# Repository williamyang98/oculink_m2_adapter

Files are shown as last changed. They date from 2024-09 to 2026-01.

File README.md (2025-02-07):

# Introduction


Open source M.2 to Oculink adapter for the Lenovo Ideapad Pro 5 16ARP8 laptop. Includes a single board design and a flexible two board design.

Documentation on design, manufacturing and benchmarks can be found [here](https://williamyang98.github.io/oculink_m2_adapter/docs/)

## Single board design
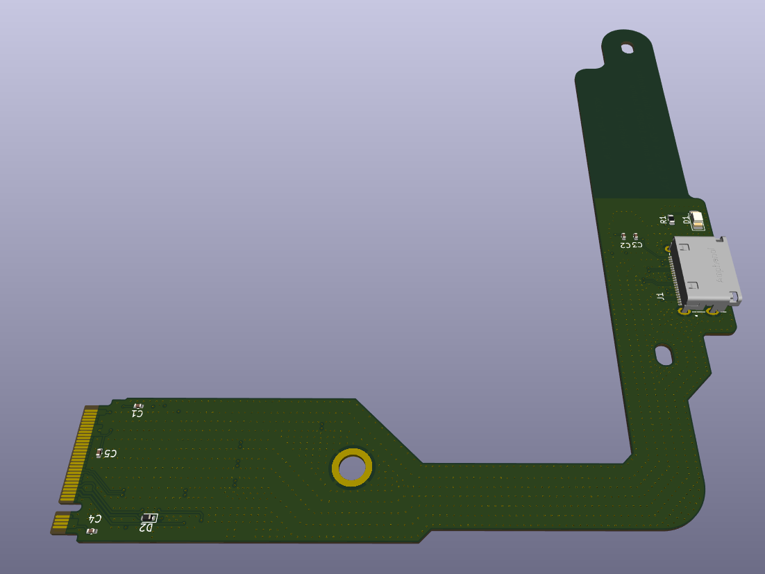
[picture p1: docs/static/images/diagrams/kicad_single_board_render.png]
Single board Oculink adapter render

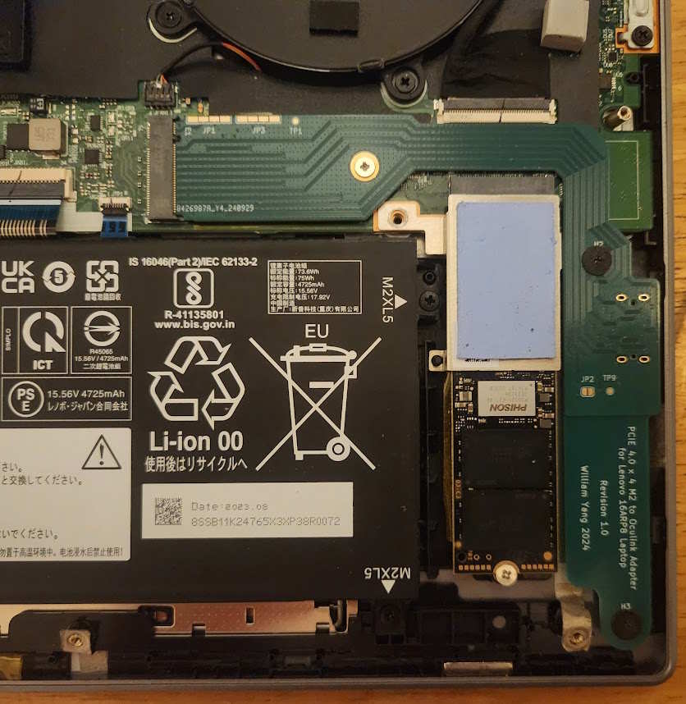
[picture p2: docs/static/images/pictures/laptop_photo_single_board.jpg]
Single board Oculink adapter


## Flexible two board design
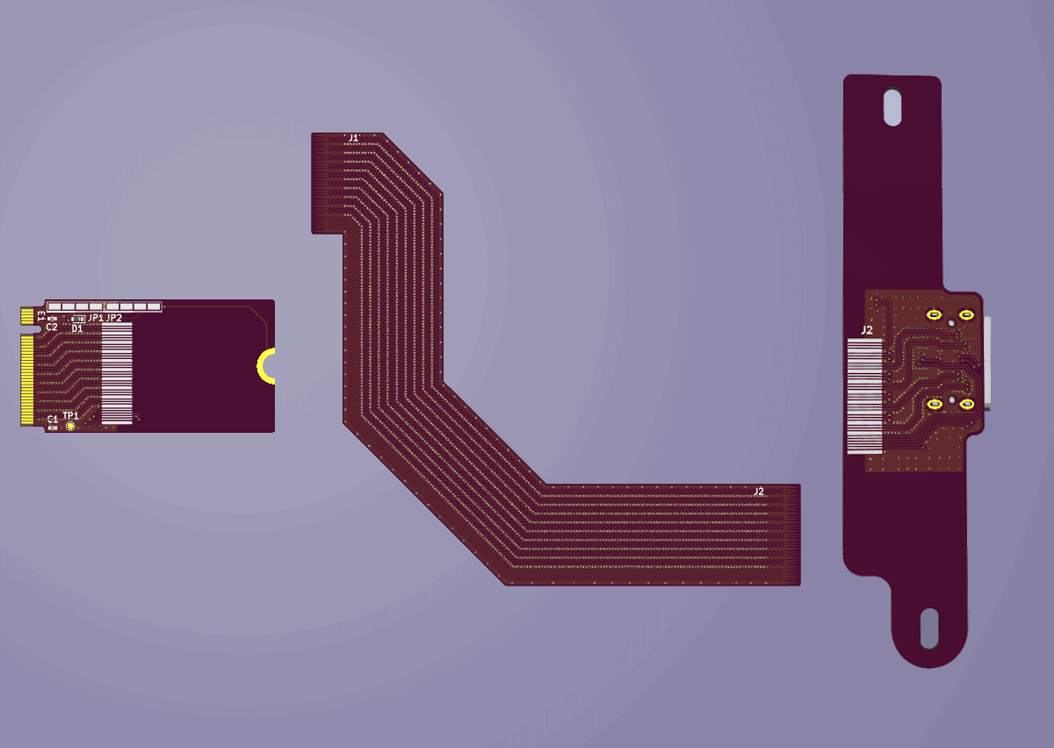
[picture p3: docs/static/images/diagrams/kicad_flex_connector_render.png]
Flexible PCB multipart Oculink adapter render

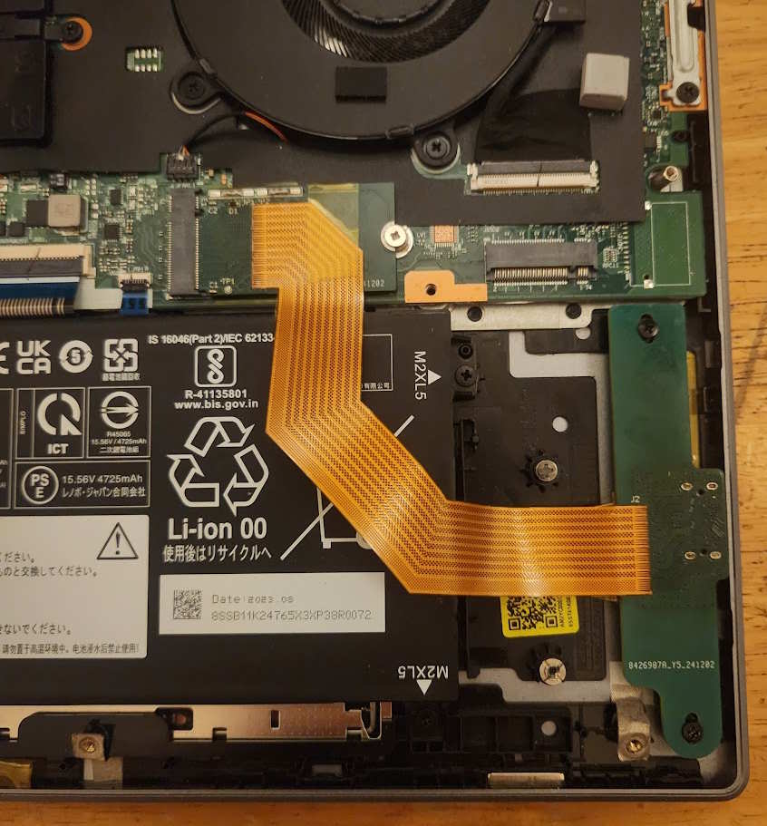
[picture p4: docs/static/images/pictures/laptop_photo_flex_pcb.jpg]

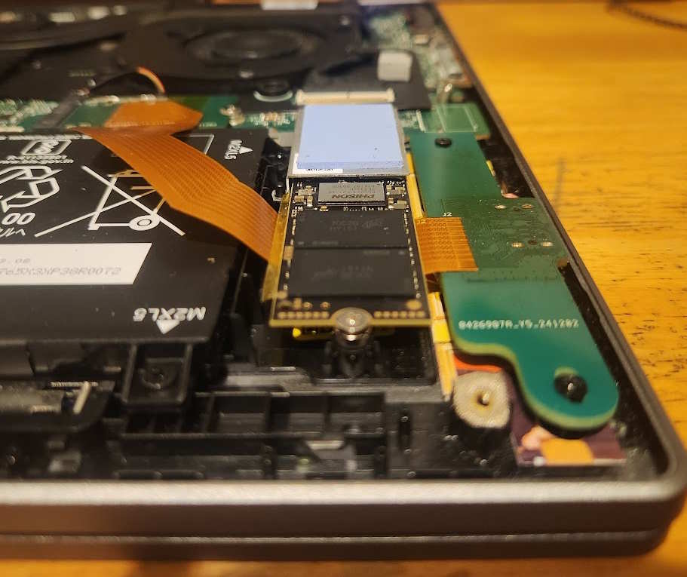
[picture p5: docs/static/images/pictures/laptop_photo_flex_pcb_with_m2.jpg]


# Project guide
| Directory | Description |
| --- | --- |
| ```docs``` | Location of hugo docs which are published to [github pages](https://williamyang98.github.io/oculink_m2_adapter/docs/) |
| ```kicad``` | Location of KiCAD schematic and PCBs files |
| ```simuations``` | Location of openEMS Python simulations for parametric optimisation of transmission line hatched ground plane and tapers |

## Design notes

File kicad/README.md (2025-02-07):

# Introduction
Contains KiCAD 8.0 schematics and PCB designs for M.2 to Oculink adapter.

| Directory | Description |
| --- | --- |
| ```custom_components``` | Includes Amphenol Oculink port KiCAD files and custom flexible PCB connector |
| ```oculink_m2_single``` | Single board M.2 to Oculink card |
| ```oculink_m2_flex_connector``` | Flexible multi-board M.2 to Oculink card |

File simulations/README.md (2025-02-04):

# Introduction
- Simulation of PCB design using ```openEMS``` and ```gerber2ems```.
- Contains KiCAD schematics for:
    - Hatched ground planes in flexible PCBs.
    - Tapered differential pair for ground plane transitions.

# Setup
1. Clone ```gerber2ems``` submodule.
```bash
git submodule update --init --recursive
```

2. Create Python 3.10 virtual environment.
```bash
# create environment
python -m venv venv
# activate environment
source ./venv/Scripts/activate
```

3. Install gerber2ems. Refer to [gerber2ems repo](https://github.com/williamyang98/gerber2ems) for more details on setup and usage.
```bash
# install vendor binaries
./gerber2ems/vendor/download.sh
# add to binaries to path
source ./gerber2ems/vendor/update_path.sh
# install gerber2ems to virtual environment
pip install -e ./gerber2ems
```

# Environment activation and deactivation
```bash
# activate environment
source ./venv/Scripts/activate
# add vendor binaries to path
source ./gerber2ems/vendor/update_path.sh
# use gerber2ems
gerber2ems -h
# deactivate environment after usage
deactivate
```

# Instructions
Refer to simulation folders for detailed instructions on how to setup and run each setup.

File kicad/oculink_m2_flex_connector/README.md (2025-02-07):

# Introduction
Contains KiCAD 8.0 schematics and PCB designs for flexible multi-PCB M.2 to Oculink adapter.

| Directory | Description |
| --- | --- |
| ```flex_pcb``` | Flexible PCB which connects M.2 card to Oculink port board |
| ```m2_card``` | M.2 2242 card |
| ```oculink_port``` | Oculink port board which is installed in left speaker position in 16ARP8 Lenovo Ideapad Pro 5 |

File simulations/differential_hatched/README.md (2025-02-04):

# Introduction
- Simulates variants of hatched ground plane for flexible PCB design.
- Refer to ```kicad/oculink_m2_flex_connector/flex_pcb``` for the final design.

# Instructions
1. Create hatched ground plane simulation variants.
```bash
python ./generate_hatches.py
```

2. Simulate hatched ground plane variants.
```bash
python ../run_simulations.py
```

3. Search for optimum hatch plane configuration.
```bash
python ../find_optimum_diffpair.py
```

# Layout
| Filepath | Description |
| --- | --- |
| ```variants_simulation/base``` | Original simulation files |
| ```variants_simulation/variants.csv``` | Stores list of variants |
| ```variants_simulation/variants/*/images/*_debug.png``` | Stores debug images of hatch ground plane variant |
| ```variants_optimum_diffpair``` | Stores S-parameter and Smith chart plots of hatch ground plane variants |

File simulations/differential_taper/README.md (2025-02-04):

# Introduction
- Simulates variants of ground taper for differential trace with ground plane transition.
- Refer to schematics in ```kicad/oculink_m2_flex_connector/``` for the final design of taper.

# Instructions
1. Create taper simulation variants.
```bash
python ./generate_tapers.py
```

2. Simulate taper variants.
```bash
python ../run_simulations.py
```

3. Search for optimum taper configuration.
```bash
python ../find_optimum_diffpair.py
```

# Layout
| Filepath | Description |
| --- | --- |
| ```variants_simulation/base``` | Original simulation files |
| ```variants_simulation/variants.csv``` | Stores list of variants |
| ```variants_simulation/variants/*/images/*_debug.png``` | Stores debug images of taper variant |
| ```variants_optimum_diffpair``` | Stores S-parameter and Smith chart plots of taper variants |

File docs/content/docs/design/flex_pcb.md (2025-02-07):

---
title: Flex connector design
prev: /docs/design/single_board
next: /docs/design/transmission_line
weight: 5
params:
  icon: bookmark
---

## Images
{{< responsive_image key="kicad_flex_connector_pcb" >}}
{{< responsive_image key="kicad_flex_connector_render" >}}

## Advantages
### Benefits of vertical routing
- Vertical routing under M.2 2280 slot has a much wider room.
- Removes requirement to move high frequency PCIe signal traces onto a different layer.
    - Avoiding additional via jumps which results in better signal integrity.
    - PCIe lanes for both RX and TX have 1 via jump.
    - This is an improvement for TX lanes over the single board design which have 2 via jumps.
- Allows adjustment of height offset of Oculink port for ideal positioning against side of laptop chassis.

### Benefits of flexible PCB connection
Flex PCB is designed to bend unlike a fibre glass core which prevents possible damage.
- Oculink port is on separate board which doesn't have to bend avoiding any possible mechanical damage to the SMD pad connections.
- Allows for more flexible positioning of the Oculink port if there is some error in the measurements.

### Polyimide dielectric
Flex PCB uses a polyimide core which potentially could have a low dielectric loss.
- Overall length of PCIe lanes is the same but majority is over the lower dielectric loss polyimide.
- Could improve signal integrity however this is difficult to verify without proper equipment.

### Flexibility of design
Easier redesign if future changes need to be made.
- M.2 card board can be kept constant.
- Flex connector can be easily redesigned and cheaply made.
- Port board can be swapped if Oculink port is damaged.
- Port board can be re-engineered to use a different PCIe compatible port like MCIO.

### Lower manufacturing cost.
Cheaper overall manufacturing compared to single board design (using JLCPCB).
- M.2 card is only 22mm x 42mm which is under 50mm x 50mm threshold resulting in $2.00USD board cost.
- M.2 card is 0.8mm which means mandatory lead free HASL that costs $4.80USD.
- Oculink port board is only 21mm x 87mm which is under the 100mm x 100mm threshold meaning no additional engineering fee.
- Oculink port board exceed 50mm x 50mm threshold which means board cost of $7.00USD.
- Oculink port board can be manufactured on a stackup thicker than 0.8mm enabling HASL with lead which is free.
- Flexible PCB connector can be manufactured at $2.00USD.
- Overall cost of $15.80USD.

## Disadvantages
### Variability in polyimide properties
Flex PCB polyimide material comes in several varieties.
- No guarantee that the polyimide used is a low dielectric loss formulation.
- JLCPCB datasheet for their polyimide supplier shows a dielectric loss which is still substantial.
- Due to thinner stackup the electric field strength is significantly higher over a thicker stackup on FR4.
- This high E-field magnitude can result in even greater dielectric losses.
- If this isn't offset by a low loss polyimide dielectric then the flex pcb may perform much worse than routing on FR4.

### Transitioning transmission line geometry
Flex pcb requires handling transition of transmission line from FR4 stackup to flex PCB stackup.
- Requires careful design to avoid impedance discontinuities at flex PCB connection.
- Involves designing transmission line tapers to maintain impedance target across connector transition.
- [Transmission line design]({{< abs_url link="docs/design/transmission_line" >}})

### Transmission line design on flex pcb
Flex pcb has a very thin dielectric core for easy bending.
- Thin dielectric means transmission line needs to be designed with extremely thin traces.
- Calculations with a solid ground plane puts trace width at < 0.05mm which is not manufacturable.
- Requires using a hatched ground plane to achieve target impedance at manufacturable 0.1mm trace width.
- Hatched ground plane needs very careful design considerations and is not trivial to design.
- [Hatched ground plane design]({{< abs_url link="docs/design/hatched_ground_plane" >}})

### Design and manufacturing complexity
Additional complexity due to multiple boards.
- More difficult manufacturing and electrical testing due to additional soldering steps for flex connector.
- More difficult design since KiCAD doesn't support multi-board designs necessitating multiple projects. 
- Requires a more complicated project layout to support sharing of common resources like the flex connector footprint.
- Requires careful design to make sure design changes are reflected across all 3 board designs (M.2 card, flex connector, Oculink port board) to avoid miswiring.

### Potential EMI issues
- Use of hatched ground plane instead of solid ground plane in flexible connector results in worse shielding at higher frequencies determined by hatch gap size.
- Since flexible pcb is routed underneath a PCIe 4.0 x 4 SSD in the M.2 2280 slot it could mean the Oculink connection will interfere with the SSD.
- Not that likely interference will be significant since the SSD also has it's own internal solid ground plane which should shield EMI between SSD and Oculink connection.

### Potential safety issue
- Flexible PCB is routed over the battery pack. In the event of a short in the Oculink connection the battery pack could be damaged and possibly ignite.
- Not that likely since PCIe connection carries low power signals and 3.3V rail isn't used to deliver any signficant amount of power to the eGPU dock.

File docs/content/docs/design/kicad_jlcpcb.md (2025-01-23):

---
title: KiCAD & JLCPCB
prev: /docs/design/laptop_measurements
next: /docs/design/single_board
weight: 3
params:
  icon: calculator
---

## Reasons to use KiCAD
- Free and open source. No license required for usage.
- More than adequate for passive M.2 to Oculink adapter.
- Transmission line calculators are limited but there are plenty of more capable free and public options.
- Lacks high end simulation capabilities like Altium but open source substitutes are available.

## Reasons to use JLCPCB
- The cheapest PCB manufacturer.
- Offers plenty of discounts for extremely low prices.
- If you stay under certain size requirements the cost will remain exceptionally low.
- Inexpensive 0.8mm thick stackup which is required for M.2 edge connector.
    - Only requires lead free HASL to be the mandatory surface finish which costs $4.80USD.
- Inexpensive board cost if certain size thresholds aren't exceeded.
    - For boards less than 50mm x 50mm board cost is only $2.00USD.
    - For boards between 50mm x 50mm and 100mm x 100mm the board cost is $7.00USD.
    - For boards above 100mm x 100mm there is an aditional engineering fee which costs $24.00USD.
- Inexpensive 4 layer boards which are important for maintaining solid ground plane if signal traces need to be routed on separate layers.
- Controlled impedance stackup to meet transmission line design requirements.
- Allows choosing denser more uniform fibre weaves to improve signal integrity in transmission lines.
    - A non-uniform weave could cause problems if a differential trace were routed over it.
    - Each side of the pair could be on a piece of the weave with different densities of fibres.
    - This would mean each trace in the pair experiences a different dielectric constant.
    - Since the speed of propagation is dependent on the dielectric constant, a skew in the time domain would be induced in the differential pair.
    - PCIe standard has relatively 
- ENIG (gold plating) to prevent oxidation of M.2 edge connector and flatter profile for more reliable reflow soldering.
- Flexible PCBs for designs that require large amounts of vertical routing.
- Very generous constraints minimum via sizes and pad pitch which is important for high frequency design where physical dimensions of traces, vias, and connector pitch can get very small.

## Importing design constraints into KiCAD
- JLCPCB specifies manufacturing capabilities.
- {{< website_link key="jlcpcb_manufacturing_capabilities" >}}
- The values for certain constraints will vary depending on options you select for the number of layers, minimum via size and stackup type.
- KiCAD supports creating a design rules file to automatically check these manufacturing constraints to prevent submitting unmanufacturable designs to a fabricator.
- The design rules checker (DRC) can be triggered manually or is run automatically before generating gerber and drill files.
- {{< website_link key="kicad_drc_file_example" >}}

## Generating gerber and drill files
- Gerber and drill files must match what the fabricator expects.
- JLCPCB specifies instructions for KiCAD 7.0 as well as other versions.
- {{< pdf_link key="jlcpcb_kicad_7_generate_gerber_and_drill_files" >}}
- Verify output through local gerber viewer program before submitting.
- Final verification in JLCPCB online gerber viewer after uploading design.

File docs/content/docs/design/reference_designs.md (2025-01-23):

---
title: Reference designs
prev: /docs/design/
next: /docs/design/laptop_measurements
weight: 1
params:
  icon: clipboard
---

## Points to verify
- Do you wire from PERxy on the M.2 side to PERxy on the Oculink side, or PERxy to PETxy?
- Do all of the control signals need to be connected?
- Is SMB (system management bus) data and clock required or is it optional?
- What about the MFG (manufacturer) data and clock on the M.2 card which is not present on the Oculink connector or PCIe standard?
- Is lane reordering and polarity inversion okay to use for routing PCIe connections?

## AdtLink M.2 to PCIe extension
{{< responsive_image key="adtlink_m2_to_pcie4_adapter_schematic" >}}
- {{< pdf_link key="adtlink_m2_pcie_x4_extension" >}}
- ```[CLKREQ, PERST]``` are connected.
- ```[PEWAKE, PEDET]``` are **not** connected.
- ```[SMB_CLOCK, SMB_DATA]``` are **not** connected.
- ```[MFG_CLOCK, MFG_DATA]``` are **not** connected.
- ```3.3V``` is connected.
- ```REFCLK``` is connected with same polarity.
- ```[PERxy, PETxy]``` lanes are connected with same polarity and same order.

## GPD Win v1 M.2 to Oculink card
{{< responsive_image key="gpdwin1_m2_to_oculink_adapter_schematic" >}}
- {{< pdf_link key="gpdwin1_schematic" >}}
- ```[PERST, PEDET]``` are connected.
- ```CLKREQ``` is connected but through a Schottky diode.
- ```PEWAKE``` is **not** connected.
- ```[SMB_CLOCK, SMB_DATA]``` are **not** connected.
- ```[MFG_CLOCK, MFG_DATA]``` are **not** connected.
- ```3.3V``` is connected through a jumper.
- ```REFCLK``` is connected with same polarity.
- ```[PERxy, PETxy]``` lanes are connected with same polarity and same order.

## Adtlink M.2 to Oculink card
{{< responsive_image key="adtlink_f4c_m2_to_oculink_adapter" >}}
{{< responsive_image key="adtlink_f4c_m2_to_oculink_adapter_photo" >}}
- {{< website_link key="adtlink_pcie4_egpu_dock" >}}
- ```[PERST, CLKREQ]``` are connected.
- ```[PEWAKE, PEDET]``` are **not** connected.
- ```[SMB_CLOCK, SMB_DATA]``` are connected.
- ```[MFG_CLOCK, MFG_DATA]``` are **not** connected.
- ```3.3V``` is connected.
- ```REFCLK``` is connected with same polarity.
- ```[PERxy, PETxy]``` lanes are connected with opposite polarity and opposite order.

## Summary
- ```PERST``` must be connected.
- ```CLKREQ``` must be connected, possibly through a diode, or shorted to ground on host side.
- ```PERST``` is optional.
- ```PEWAKE``` is not connected (might be optional?).
- ```[SMB_CLOCK, SMB_DATA]``` are optional.
- ```[MFG_CLOCK, MFG_DATA]``` are not connected.
- ```3.3V``` is connected.
- ```REFCLK``` must be connected with same polarity.
- ```[PERxy, PETxy]``` can be connected in opposite polarity and/or opposite order.

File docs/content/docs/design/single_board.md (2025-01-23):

---
title: Single board design
prev: /docs/design/kicad_jlcpcb
next: /docs/design/flex_pcb
weight: 4
params:
  icon: bookmark
---

## Images
{{< responsive_image key="kicad_single_board_pcb" >}}
{{< responsive_image key="kicad_single_board_render" >}}

## Advantages
### Simpler design
- Easier manufacturing and testing since we only need to solder the Oculink port and passive components.
- Single KiCAD schematic required allowing for easier design inside single project.
- Requires only a single transmission line to be designed reducing design complexity.

### More reliable performance
- Having multiple boards connected over a flexible PCB adds additional potential impedance discontinuities.
- Without equipment to verify performance at PCIe 3.0+ frequencies it is difficult to validate performance.
- Introducing fewer design uncertainties will make final performance more likely to align with calculations.

## Disadvantages
### Narrow routing resulting in layer transition
PCIe signal lanes have to fit through a very narrow region which requires routing differential pairs onto other layers.
- Requires careful design of via jumps to prevent impedance mismatch and signal reflection.
- PCIe RX lanes have 1 via jump and PCIe TX lanes have 2 via jumps.
- Each additional via jump will worsen signal integrity so having 2 is unideal.

### Port location and bending
Board has to be slightly bent so that Oculink port is at the correct height with laptop chassis.
- Might result in damage to circuit if the board isn't flexible enough.
- Could result in degraded transmission line performance due to stretching of traces and introduction of inter-pair skew in differential pairs.
- Could result in Oculink port pad connection breaking due to uneven mechanical stress.

### Long distance routing
PCIe lanes have to be routed over a moderately long distance (12cm).
- We are using FR4-TG135 which has a high dielectric loss at high frequencies.
- If we are targetting PCIe 4.0 then we need to handle the 5th harmonic of the fundemental frequency which is 40GHz.
- It is highly unlikely to maintain PCIe 4.0 over such a long distance with a high loss dielectric.

### Large size
Single board design is relatively large.
- M.2 slot requires 0.8mm thickness which results in mandatory lead free HASL that costs $4.80USD.
- Exceeds 50mm x 50mm threshold meaning board goes from $2.00USD to $7.00USD.
- Exceeds 100mm x 100mm threshold meaning additional engineering fee of $24.00USD.
- Overall cost of $35.80USD.

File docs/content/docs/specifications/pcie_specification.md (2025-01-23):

---
title: PCIe Specification
prev: /docs/specifications/
next: /docs/specifications/components
weight: 1
params:
  icon: lightning-bolt
---

## PCIe pinout
- Differential signalling along receive (RX) and transmit (TX) lanes.
    - Polarity of lanes can be inverted.
    - Order of lanes can be reversed between host and device.
    - Number of RX and TX lanes must be the same (symmetrical).
    - Allows for more flexible routing in space constrained environment.
- Reference clock is provided from host for timing and synchronisation (100MHz).
    - Polarity cannot be swapped.
    - Supposed to be optional but is actually mandatory for almost all devices.
- ```CLKREQ``` is pull downed by device to request PCIe reference clock.
- ```PERST``` is used to reset the PCIe link.
- ```PEWAKE``` is used by device to signal to host to wake up (maybe for network cards?).
- ```SMBCLK``` and ```SMBDAT``` is the system management bus and is an I2C interface (optional?)

{{< responsive_image key="pcie_x4_pinout" >}}

## PCIe generations
- With differential signalling the fundemental frequency is half the transfer rate.
- An encoding scheme of xb/yb means X bits out for Y bits in.
    - 8b/10b: 1 start bit, 8 data bits, 1 end bit.
    - 128b/130b: 1 start bit, 128 data bits, 1 end bit.

| Gen | Freq (GHz) | Transfers (GT/s) | Encoding | Bitrate (Gb/s/lane) |
| --- | --- | --- | --- | --- |
| 1.0 | 1.25 | 2.5 | 8b/10b | 2.0 |
| 2.0 | 2.5 | 5.0 | 8b/10b | 4.0 |
| 3.0 | 4.0 | 8.0 | 128b/130b | 7.88 |
| 4.0 | 8.0 | 16.0 | 128b/130b | 15.75 |
| 5.0 | 16.0 | 32.0 | 128b/130b | 31.51 |

- {{< website_link key="pcie_fibermall" >}}

## Maximum design frequency
For a good eye opening the transmissions lines should be designed for 5x the fundemental frequency. For PCIe 4.0 the fundamental frequency is 8GHz which means an ideal maximum design frequency of 40GHz.

{{< responsive_image key="altium_eye_diagram" >}}

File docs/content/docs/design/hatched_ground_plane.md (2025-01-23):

---
title: Hatched ground plane
prev: /docs/design/transmission_line
next: /docs/manufacturing
weight: 7
params:
  icon: hashtag
---

## Stackup
- Very thin dielectric core
- Means very difficult to attain correct impedance without making traces extremely thin with a solid ground plane
- Thicker dielectric cores are provided but they increase cost substantially and trace width is still too thin to manufacture

## Hatched ground plane
- Hatched ground plane can allow for wider traces while matching impedance
- No easy equation to get impedance measurement (fill factor approximation does not model this adequately)
- Requires parametric search with simulation software
- Design of hatched ground plane must meet manufacturing capabilities of JLCPCB

## openEMS simulation
- Many ways to set up simulation
    - Fixed trace width, vary hatch geometry
    - Fixed hatch geometry, vary trace width
    - Select fixed trace width since that is easier to transition to from an existing known trace width on parent boards
- Parametric search by varying hatch width and gap
    - Routing of differential traces over hatch ground plane must be symmetrical otherwise inter-pair skew will result in bad performance
    - Termination of hatched ground plane to SMD pads requires taper to avoid impedance discontinuity and reflections
- Limits in resolution and speed of openEMS due to CPU based design (GPU acceleration not available)
- Ansys supports CUDA acceleration but is difficult to use with exported gerber files
- OpenEMS can be used with a python toolchain to process and setup openEMS harness with gerber files and drill files

## Results
- Table of results
- Graph of impedance

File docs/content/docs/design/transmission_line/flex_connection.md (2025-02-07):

---
title: Flex connection
prev: /docs/design/transmission_line/hatched_ground_plane
next: /docs/design/transmission_line/calculations
weight: 7
params:
  icon: hashtag
---

## Type of connection
### Flexible flat/printed cable connector
{{< responsive_image key="molex_ffc_fpc_connector" >}}
<table>
  <thead>
    <tr>
      <th style="width: 50%">Advantages</th>
      <th style="width: 50%">Disadvantages</th>
    </tr>
  </thead>
  <tbody style="vertical-align: top">
    <tr>
      <td>
        <ul>
          <li>Flexible connector can be replaced without resoldering the connector.</li>
          <li>Allows for easier installation and removal without danger of damaging flexible connector.</li>
        </ul>
      </td>
      <td>
        <ul>
          <li>Requires designing transmission line to gracefully transition to the connector without a large impedance discontinuity.</li>
          <li>Higher insertion loss compared to soldered connection since contact surface isn't perfect and there will be stubs from the internal connectors. This could hamper high frequency performance.</li>
          <li>Maximum usable frequency before insertion loss is more than 3dB is usually below 20GHz. This is the recommended design frequency for a good eye opening for PCIe 3.0 which has a fundemental frequency of 4GHz.</li>
          <li>Requires reflow soldering the connector which is extremely difficult for a fine pitch connector (0.2mm) without risk of bridging.</li>
          <li>Connectors add a few extra dollars of cost to the bill of materials</li>
        </ul>
      </td>
    </tr>
  </tbody>
</table>

- {{< pdf_link key="molex_ffc_fpc_datasheet" >}}

### Soldered connection
<table>
  <thead>
    <tr>
      <th style="width: 50%">Advantages</th>
      <th style="width: 50%">Disadvantages</th>
    </tr>
  </thead>
  <tbody style="vertical-align: top">
    <tr>
      <td>
        <ul>
          <li>Allows for more control over the design of the transmission line structure</li>
          <li>Lower insertion loss since connection is soldered. This means no stubs caused by extra internal connector pins or non-ideal/non-uniform contact surface.</li>
          <li>Connector SMD pads can be designed specifically to avoid discontinuities in impedance caused by trace length mismatch, loss of coplanar ground traces or ground plane.</li>
        </ul>
      </td>
      <td>
        <ul>
          <li>Low tolerance for z-height error on pad connections requires soldering the connector very flat to the SMD pads. This may require pressure during the reflow process</li>
          <li>Requires hand positioning of flexible connector onto pads which is extremely difficult since the traces are only 0.1mm. Any pitch error will result in possible bridging or degraded signal integrity</li>
          <li>Flexible pcb is not removable and is permanently connected to the boards. This might make installation or removal more difficult if connector is in a suboptimal location.</li>
        </ul>
      </td>
    </tr>
  </tbody>
</table>

### Final choice
The **soldered connection** allows closer control over the design of the tranmission line and avoids the downsides of a FFC connector. This should allow us to avoid or mitigate the signal integrity issues that will arise from the use of a FFC connector.

## Structure of transmission line
{{< responsive_image key="sierra_express_coplanar_ground_plane_via_fence_transmission_line" >}}

The following are useful equations to describe the impedance of the transmission line in relation to it's geometry. These will be useful in determining which parameters to adjust if we want to meet our PCIe impedance target. This comes at the cost of lower modularity but is this is an acceptable compromise for higher guarantees of high frequency signal performance.

### Characteristic impedance
Rough equation for a simple transmission line is given by:

{{< mathjax body >}}
Z_0 = \sqrt{\frac{L}{C}}
{{< /mathjax >}}

This is still useful when discussing changes in impedance for a variety of transmission line structures if we discuss them in terms of differing trace inductances and capacitances.

{{< website_link key="university_san_diego_characteristic_impedance" >}}

### Parallel plate capacitors
The capacitance between a simple two plate system is given by:
{{< mathjax body >}}C = \frac{\epsilon_0 A}{d}{{< /mathjax >}}

{{< responsive_image key="parallel_plate_capacitor" >}}

### Wire over plane
The inductance of a wire over a plane can be approximated as:
{{< mathjax body >}}L = \frac{\mu_0 \mu_r d}{2 \pi} cosh^{-1}{\frac{h}{2r}} {{< /mathjax >}}

{{< responsive_image key="wire_plane_inductance" >}}

## Stackup height differences
{{< responsive_image key="jlcpcb_stackup_diagram" >}}

Transitioning our transmission line from an FR4 stackup to a flexible PCB stackup causes the height of the dielectric in the transmission line to significantly decrease.
- Therefore signal trace to ground plane capacitance increases which causes impedance to decrease.
- Mismatch in impedance causes signal reflections and reduced integrity.

### Hatched ground plane
If the transmission line signal traces have the same width, using a suitably designed hatched ground plane will increase the impedance to meet our impedance target. 
- See [designing hatched ground plane]({{< abs_url link=docs/design/transmission_line/hatched_ground_plane >}}) for more details.
- See [simulating hatched ground plane]({{< abs_url link=docs/design/open_ems/hatched_ground >}}) for more details.

## Vertical transmission line connection
{{< responsive_image key="jlcpcb_stackup_connection" >}}
Transition from FR4 stackup to flexible PCB involves a vertical solder connection which produces an impedance discontinuity.

- The coplanar ground traces experience some discontinuity when it meets the solder connection due to an increase in the conductor height.
    - Results in an increase in edge coupling area.
    - This increases capacitance and decreases impedance.
- The E-fields between the signal traces and ground planes have to switch layers.
    - Broadside coupling means stronger E-fields and more energy being carried compared to the coplanar ground traces which use edge coupling.
    - Capacitive coupling is greater through a broadside connection since the traces are 0.1mm wide, compared to the edge side coupling which occurs over a 0.012mm or 0.035mm
    - This was verified through an [open EMS simulation]({{< abs_url link="docs/design/open_ems/" >}}).

### Tapered connection
{{< responsive_image key="flex_pcb_transmission_line_taper" >}}

A taper is a gradual change in the geometry of a transmission line that attempts to maintain consistent impedance value across a geometric transition.
- We use a linear taper to transition the E-field broadside coupling from the ground plane on the M.2 card to the ground plane on the flexible PCB.
- A linear taper is not necessarily the best however it is very simple to design.
    - {{< website_link key="altium_rf_trace_taper" >}}
    - Other taper designs have complex non-linear equations describing their shape which is difficult to import/design using KiCAD.
    - Linear taper just requires the polyline tool in KiCAD.

### Parametric optimisation of taper
To verify the performance of the taper [openEMS]({{< abs_url link="docs/design/open_ems/taper" >}}) was used.
- Simulated stackup with flex PCB connected to FR4 transmission line as a 3 layer board.
    - Layers were: ```[FR4 ground, signal traces, flex PCB ground]```.
    - The soldered signal traces were approximated as an ideal single trace on a single layer.
    - This was done so that only the E-field transition between the ground planes was relevant for our parametric search.
    - Might not be ideal from a simulation accuracy standpoint as the geometry of the solder connection might impact the impedance match. However representing the solder connection in our simulation setup was difficult so this approximation/assumption was used.
- Parametric search was done on the length, width, and amount of overlap of the linear taper.
- Shape of taper was modified separately on the FR4 stack up and flexible PCB stackup.
- Possible that simulation was not accurate since mesh size is limited and linear taper requires very small simulation grid size to accurately capture the pointy part.

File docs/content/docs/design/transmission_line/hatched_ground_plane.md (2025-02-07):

---
title: Hatched ground plane
prev: /docs/design/transmission_line/skew_requirements
next: /docs/design/transmission_line/flex_connection
weight: 6
params:
  icon: hashtag
---

## Problems with thin flexible PCB
- The base polyimide dielectric core has a thickness of 25um.
- This means that we need extremely thin traces with a solid ground plane if we want to reach our PCIe impedance target.
- Thicker dielectric cores are provided but they increase cost substantially and trace width barely increases.
- Even worse the calculated transmission line trace width is calculated as 0.05mm which is below JLCPCB's manufacturing minimums.

## Hatched ground plane
- Hatched ground plane can allow for wider traces while matching impedance.
- No easy equation to get impedance measurement (fill factor approximation does not model this adequately).
- Design of hatched ground plane must meet manufacturing capabilities of JLCPCB.
- Requires parametric search with simulation software.
- Refer to this section about simulating circuits with [openEMS]({{< abs_url link="docs/design/open_ems/hatched_ground" >}}).

## Determining parameters
There are three major parameters to consider:
1. Trace width.
2. Hatch width.
3. Hatch gap.

Since we need to be above the minimum trace width for JLCPCB to manufacture it, we should select a fixed trace width of 0.1mm.
- This is similar the trace width of 0.13mm for our transmission line on the FR4 substrate for both the M.2 cad and Oculink port board.
- This means we will have an easier time designing a taper geometry when connecting the flex connector to our boards (discussed [here]({{< abs_url link="docs/design/transmission_line/flex_connection" >}})).
- Means we only need to perform a parametric search with two variables (the hatch width and gap) which is less time consuming.

## Additional design considerations
Refer to minimising [intra-pair skew]({{< abs_url link="docs/design/transmission_line/skew_requirements#hatched-ground-plane" >}}) for hatched ground planes and differential pairs.

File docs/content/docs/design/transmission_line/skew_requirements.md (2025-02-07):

---
title: Skew requirements
prev: /docs/design/transmission_line/skin_effect
next: /docs/design/transmission_line/hatched_ground_plane
weight: 5
params:
  icon: switch-horizontal
---

The PCIe standard specifies several requirements for differential pair skew.

## Inter-pair skew (between lanes)
Inter-pair skew is usually not specified but has a lower bound of 1ns for PCIe 4.0.
- Assuming a propagation speed of 0.6c, the inter-pair skew is around 20cm.
- Since this is such a large value the inter-pair skew requirement is difficult to violate. 
- The reason for this is because the PCIe standard states that transceivers have to do symbol synchronisation.
- Usually done with a buffer which usually can store around 20 symbols for each lane.
- For PCIe 4.0 at a transfer rate of 16GT/s, 20 symbols have a duration of 1.25ns.

## Intra-pair skew (within lane)
Intra-pair skew must be less than 5 mils (0.127mm) which is rather small margin of error.
The following are phenomena that can contribute to intra-pair skew and methods to mitigate them.

### Bends in transmission line
{{< responsive_image key="sierra_express_length_matching" >}}

- Bending causes the lengths of differential traces to become shorter and longer resulting in skew.
- Can be avoided by keeping bends short so local skew error is below 5 mils.
- If skew error is too large than it should be immediately corrected near the bend by adding serpentine bends for the shorter side of the differential pair.
- KiCAD can automatically do this using their skew correction tool.

### Fibre weave effect
{{< responsive_image key="fibre_weave_skew_time_domain" >}}
{{< responsive_image key="fibre_weave_skew_eye_opening" >}}

- {{< website_link key="signal_integrity_skew_budget" >}}
- {{< website_link key="cadence_fibre_weave_effect" >}}
- A poor choice of a dielectric with a non-uniform fibre weave pattern can result in large intra-pair skews.
- There is also no method of designing the circuit around a bad fibre weave since the manufacturer cannot position the weave at a specific offset.

#### Better fibre weave patterns
{{< responsive_image key="fibre_weave_patterns" >}}
{{< responsive_image key="altium_fibre_weave_flattened" >}}

- There should be careful selection of an appropriate fibre weave pattern for maximum uniformity.
- Additionally there is also mechanically compressed fibre glass which flattens the weave and fills in any gaps to produce a uniform weave pattern.
- Here is a pdf from Isola group who are a copper clad laminate and prepreg materials manufacturer.
    - {{< pdf_link key="isola_group_fibre_weave_patterns" >}}
    - It contains various high quality images of fibre weave patterns and their fill factor measurements.
    - They also include treatment processes for bonding the prepreg and core to copper layers and how that effects the copper smoothness which is relevant for [skin effect]({{< abs_url link="docs/design/transmission_line/skin_effect" >}}).

#### JLCPCB controlled impedance stackup
{{< responsive_image key="jlcpcb_controlled_impedance_stackup_weave_patterns" >}}

- JLCPCB offers a variety of fibre weave patterns when a multilayer controlled impedance stackup is requested (this is also free).
- It is also possible to stack two or more fibre weaves vertically to increase overall density and improve uniformity.

### Hatched ground plane
{{< responsive_image key="hatched_ground_plane_unbalanced" >}}

- For hatched ground planes in a flexible pcb design asymmetric routing can produce large intra-pair skews.
- For straight transmission line routes it is trivial to route the differential pair symmetrically.
- However if the transmission line needs to bend then the hatched ground plane needs to warp to avoid introducing skew.
- This is exceptionally difficult to do with KiCAD's built in hatched ground fill tool.
- Requires manual layout and distortion of hatched ground plane to accomodate bends in a differential pair.

{{< responsive_image key="hatched_ground_plane_manual_differential_bend" >}}

- Unfortunately KiCAD's built in skew correction tools cannot measure skew for hatched ground planes generated manually or automatically by their ground fill tool.
- This makes verification of the intra-lane skew extremely difficult at the design stage.

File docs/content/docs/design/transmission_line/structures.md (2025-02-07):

---
title: Structures
prev: /docs/design/transmission_line
next: /docs/design/transmission_line/via_fence
weight: 1
params:
  icon: switch-horizontal
---

PCIe receive and transmit lanes and reference clock are high frequency differential signals. There are many possible designs for a differential transmission line.

{{< responsive_image key="sierra_express_differential_pair_topologies" >}}

## Common mode noise
In theory a perfectly balanced differential pair would only need two conductors to handle the symmetrical current path however this should not be relied upon.
- Common mode noise can arise due to power supply differences between host and device. This is especially important because we have a laptop powered by a USB C dock and an eGPU powered by a separate power supply.
- Without a ground plane or coplanar ground trace the return current for the common mode signal may be over a large loop area.
    - This can pickup interference from environmental sources and harm signal integrity.
    - Increases amount of EMI induced in signal traces within that loop area.

## Crosstalk
Given our tight routing requirements our PCIe lanes would be extremely close together by only a few multiples of the trace width. This means we need to be very careful about inter-lane crosstalk.
- Can be fixed by increasing separation between lanes which is not possible given our tight space requirements.
- Adding a ground plane to confine the electric field generated by the differential pair (almost always helps).
- Adding coplanar guard traces to separate adjacent lanes and add additional E-field confinement.
    - Sometimes can worsen crosstalk if guard trace is high impedance and functions closer to a resonant tank than a ground trace.
    - Can be improved by turning coplanar guard traces into a [via fence]({{< abs_url link="docs/design/via_fence" >}}) by stitching them to a ground plane 
    - This guarantees coplanar guard trace is low impedance.
    - Also adds additional grounding with vias which further improves E-field confinement and prevents inter-lane crosstalk.

## Best design
The following should be used for an optimal differential pair transmission line:
- Solid ground plane
- Coplanar guard traces
- Via fence 

Through this we should be able to reduce crosstalk, handle common mode noise, and reduce EMI emissions even with tightly packed PCIe lanes.

## Resources
- {{< pdf_link key="texas_instrument_pcie4_layout_guidelines" >}}

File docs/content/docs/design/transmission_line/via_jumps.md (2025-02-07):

---
title: Via jumps
prev: /docs/design/transmission_line/via_fence
next: /docs/design/transmission_line/skin_effect
weight: 3
params:
  icon: switch-horizontal
---

- Via jumps are necessary if a transmission line needs to switch lanes. 
- In order to avoid signal reflections the characteristic impedance of the transmission line needs to remain constant when traversing from between layers through a via.

## Coaxial via
{{< responsive_image key="via_jump_diagram" >}}

- If there are no nearby grounding vias then a distant current return path is used which results in a significant impedance mismatch.
- Instead we add nearby grounding vias to provide a current return path.
- This type of via structure is called a coaxial via.
- The following parameters are important when trying to control the impedance of a coaxial via:
    - Distance of ground vias from signal via.
    - Number of ground vias around the signal via.
    - Hole size of the ground via and signal via.
    - Dielectric material used to fill the vias.

## Teardrop taper
{{< responsive_image key="via_jump_pcb" >}}

- When a signal trace goes through a via there is an impedance discontinuity especially if the trace width and via diameter are different.
- Adjusting the following can reduce the impedance discontinuity:
    - Adding a teardrop taper to match trace width to via diameter.
    - Adjusting the via annular diameter.
    - Adjusting the via hole size.

## Determining parameters
- There is no closed form equation for the impedance of a coaxial via with a teardrop taper.
- This means running a parametric search through a simulation to determine the optimal parameter values.
- Very difficult to do given the number of parameters for the coaxial via and teardrop taper which all impact performance.
- Refer to this section about simulating circuits with [openEMS]({{< abs_url link="docs/design/openEMS" >}}).

## Via stubs
{{< responsive_image key="sierra_express_via_stub_back_drilling" >}}

- If via jump isn't between the top and bottom layers then there will be a stub segment in the via.
- This will have the most signficant impact at the following frequency:

{{< mathjax body >}}
f_0 = \frac{c}{4 \sqrt{\epsilon_r} \times d_{stub}}
{{< /mathjax >}}

- Actual performance degradation happens well before this frequency.
- By decreasing {{< mathjax >}}d_{stub}{{< /mathjax >}} we can increase {{< mathjax >}}f_0{{< /mathjax >}} well past our maximum design frequency and avoid problems.
- If the via stub is sufficiently short then it will not have a noticeable impact on signal integrity below our maximum design frequency.

## Buried, blind and through hole vias
{{< responsive_image key="jlcpcb_what_is_pcb_via" >}}

- Buried and blind vias can be used to avoid via stubs.
- These types of vias can be manufactured using a technique called backdrilling.
- However JLCPCB only supports through hole vias.

## Resources
- {{< website_link key="sierra_coaxial_via" >}}
- {{< website_link key="samtec_blog_via_stub" >}}
- {{< website_link key="altium_backdrilling_stubs" >}}

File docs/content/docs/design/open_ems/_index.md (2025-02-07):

---
title: OpenEMS
prev: /docs/design/transmission_line/calculations
next: /docs/design/open_ems/hatched_ground
weight: 7
params:
  icon: switch-horizontal
---

{{< toc >}}

- For an explanation of how to run the parameter search refer to [simulations/README.md](https://github.com/williamyang98/oculink_m2_adapter/blob/main/simulations/README.md).
- To understand how to use gerber2ems refer to [williamyang98/gerber2ems](https://github.com/williamyang98/gerber2ems).

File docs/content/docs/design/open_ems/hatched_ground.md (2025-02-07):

---
title: Hatched ground
weight: 1
prev: /docs/design/open_ems/
next: /docs/design/open_ems/taper
---

## Simulation setup
{{< responsive_image key="openems_hatched_debug" >}}
{{< responsive_image key="openems_hatched_3d" >}}

- Various geometries were auto-generated by a Python script which produced image files with different hatch configurations.
- These were then given to gerber2ems to simulate using openEMS.
- A parametric search over the hatch width and gap amount for the optimum search was performed.

## Parameter search
{{< responsive_image key="openems_hatched_s_params" >}}
{{< responsive_image key="openems_hatched_reflectance" >}}

- The configuration with the lowest mean energy loss in our frequency range of interest (0GHz to 40GHz) was chosen.
- This was repeated for a range of different hatch widths, and the optimum out of these was then chosen.

{{< responsive_image key="openems_hatched_s_params_overall" >}}
{{< responsive_image key="openems_hatched_reflectance_overall" >}}

## Discussion
- The average reflectance seemed to have a minimum offset of ```Γ = 0.1``` which was probably due to the bad impedance match when transitioning from the solid ground plane to hatched ground plane in the simulation.
- Highly likely that this would also occur in our flexible PCB since there is also a similar transition at the soldered connection.
- Doesn't simulate dielectric loss or skin effect which is important for predicting how lossy the design is, especially at higher frequencies where these effects are significant.
    - Right now the gerber2ems script uses a perfect conductor as the metal material, however openEMS has [ConductingSheet](https://wiki.openems.de/index.php/Metal_Property.html) which simulates conductivity for lossy conductors.
    - Both dielectric loss and skin effect losses increase at higher frequencies however conductivity is flat across all frequencies, which makes it unsuitable for simulating these lossy effects.

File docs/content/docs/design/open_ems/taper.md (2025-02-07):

---
title: Taper
weight: 2
prev: /docs/design/open_ems/hatched_ground
next: /docs/manufacturing
---

## Simulation setup
{{< responsive_image key="openems_taper_debug" >}}
{{< responsive_image key="openems_taper_3d" >}}

- Various geometries were auto-generated by a Python script which produced image files with different hatch configurations.
- These were then given to gerber2ems to simulate using openEMS.
- A parametric search over the width, length and overlap amount for the optimum search was performed.
- The overlap was a percentage of the length of the taper. E.g. ```[0.5, 1.0, 1.5]```.

## Parameter search
{{< responsive_image key="openems_taper_s_params" >}}
{{< responsive_image key="openems_taper_reflectance" >}}

- The configuration with the lowest mean energy loss in our frequency range of interest (0GHz to 40GHz) was chosen.
- This was repeated for fixed width and length parameters, then for fixed width paramters, after which the optimum was then chosen.

{{< responsive_image key="openems_taper_s_params_overall" >}}
{{< responsive_image key="openems_taper_reflectance_overall" >}}

## Discussion
- Doesn't simulate dielectric loss or skin effect which is important for predicting how lossy the design is, especially at higher frequencies where these effects are significant.
- Right now the gerber2ems script uses a perfect conductor as the metal material, however openEMS has [ConductingSheet](https://wiki.openems.de/index.php/Metal_Property.html) which simulates conductivity for lossy conductors.
- Limited resolution of the openEMS simulation meant that the infinitely pointy taper could not be simulated. This probably resulted in inaccurate simulated performance at higher frequencies.

### Limitations
- This taper is supposed to be used to transition from the transmission line on the FR4 PCB to the flexible polyimide PCB.
- The thickness of the copper layer would need to be considered, however due to bugs in the gerber2ems simulation setup it is difficult to guarantee stable/correct results when connecting the micro stripline simulation port to a 3D metal mesh.
- An accurate simulation would require adding in the FR4 stackup and polyimide stackup including the solder bridge connecting the two PCB together. This would require gerber2ems to support much more complicated stackups.
- A hatched ground plane would need to be added to simulate how the taper behaves with a hatched ground plane.

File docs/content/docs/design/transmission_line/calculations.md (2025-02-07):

---
title: Calculations
prev: /docs/design/transmission_line/flex_connection
next: /docs/design/open_ems/
weight: 8
params:
  icon: calculator
---

## JLCPCB data
### Soldermask
| Location | Thickness (mil) | Thickness (mm) |
| --- | --- | --- |
| Laminate | 1.2 | 0.03048 |
| Traces | 0.6 | 0.01524 |

Dielectric constant = 3.8

### Core dielectric
Dielectric constant = 4.6

- [JLCPCB impedance control stackup information](https://jlcpcb.com/impedance?_t=1727251667361)
- [JLCPCB impedance calculator guide](https://jlcpcb.com/help/article/User-Guide-to-the-JLCPCB-Impedance-Calculator)

### JLC04081H-3313 Stackup
#### Name breakdown
| Part  | Meaning |
| --- | --- |
| 04 | 4 layer |
| 08 | 8mm thickness |
| 1 | 1oz outer copper |
| H | half (0.5oz) inner copper |
| 3313  | 3133 prepreg |

#### Stackup information
| Layer | Material Type | Thickness (mm) |
| --- | --- | --- |
| Trace | Copper | 0.035 |
| Prepreg | 3313x1 | 0.0994 |
| Inner Layer | Copper | 0.0152 |
| Core | Core | 0.45 |
| Inner Layer | Copper | 0.0152 |
| Prepreg | 3313x1 | 0.0994 |
| Trace | Copper | 0.035 |

### Core material properties
Nan Ya Plastics NP-155F (4 to 8 layers)

| Core Thickness (mm) | εr |
| --- | ---  |
| 0.08 | 3.99 |
| 0.10 | 4.36 |
| 0.13 | 4.17 |
| 0.15 | 4.36 |
| 0.20 | 4.36 |
| 0.25 | 4.23 |
| 0.30 | 4.41 |
| 0.35 | 4.36 |
| 0.40 | 4.36 |
| 0.45 | 4.36 |
| 0.50 | 4.48 |
| 0.55 | 4.41 |
| 0.60 | 4.36 |
| 0.65 | 4.36 |
| 0.70 | 4.53 |
| > 0.70 | 4.43 |

### Prepreg
#### Source 1
| Prepreg Type  |  Resin Content |  Nominal Thickness (mil) | εr |
| --- | --- | --- | ---  |
| 7628 | 49% | 8.6 | 4.4  |
| 3313 (2313) | 57% | 4.2 | 4.1  |
| 1080 | 67% | 3.3 | 3.91 |
| 2116 | 54% | 4.9 | 4.16 |

#### Source 2
| Prepreg type  | Dielectric constant |
| --- | --- |
| 7628 | 4.6 |
| 3313 | 4.05 |
| 2116 | 4.25 |

### Impedance calculator results
[JLCPCB impedance calculator](https://jlcpcb.com/pcb-impedance-calculator)

| Parameter | Value |
| --- | --- |
| Layers | 4 |
| Thickness | 0.8mm |
| Inner copper weight | 0.5oz |
| Outer copper weight | 1.0oz |
| Stackup | JLC04081H-3313 |

**NOTE**: Core is 0.5mm instead of expected 0.45mm which might reduce accuracy of calculations.

#### Trace thicknesses
| Impedance (Ω) | Type | Config | Trace width (mm)  | Trace spacing (mm) | Distance coplanar (mm) |
| --- | --- | --- | --- | --- | --- |
| 85 | Coplanar differential pair with ground | L1-L2 | 0.1549 | 0.15 | 0.15 |
| 85 | Coplanar differential pair with ground | L2-L3-L4  | 0.1334 | 0.15 | 0.15 |
| 42.5 | Coplanar single ended with ground | L1-L2 | 0.1971 | N/A | 0.15 |
| 42.5 | Coplanar single ended with ground | L2-L3-L4  | 0.1679 | N/A | 0.15 |

## Sierra circuits calculations
[Sierra circuits impedance calculator](https://impedance.app.protoexpress.com/)

### Prepreg dielectric material property
Rigid - FR408HR - Prepreg
| Parameter | Value |
| --- | --- |
| Dielectric thickness | 4.2? |
| Construction | 1x3313-59% |
| Resin content | 59% |

| Frequency (GHz) | Dielectric constant | Dissipation factor |
| --- | --- | --- |
| 1 | 3.58 | 0.009 |
| 2 | 3.57 | 0.009 |
| 5 | 3.55 | 0.010 |
| 10 | 3.54 | 0.010 |
| 20 | 3.54 | 0.010 |

### Coplanar stripline differential pair with ground plane
[Impedance calculator](https://impedance.app.protoexpress.com/?appid=CPSLDPIMPCAL)

| Parameter | Value |
| --- | --- |
| Configuration | L2-L3-L4  |
| L2-L3 dielectric height (mm)  | 0.0994 |
| L2-L3 dielectric constant | 3.55 |
| L3-L4 dielectric height (mm)  | 0.45 |
| L3-L4 dielectric constant | 4.4 |
| L3 Trace thickness (mm) | 0.01524 |
| L3 Trace separation (mm) | 0.15 |
| Conductor spacing (mm) | 0.15 |
| Conductor width (mm) | 0.6 |
| Dielectric covering tracks | L2-L3 |

| Input parameter | Input value | Output parameter  | Output value  |
| --- | --- | --- | --- |
| Zdiff (Ω) | 85 | Trace width (mm)  | 0.1372 |
| Trace width (mm)  | 0.1334 | Zdiff (Ω) | 85.88 |

### Coplanar soldermask coated microstrip differential pair with ground plane
[Impedance calculator](https://impedance.app.protoexpress.com/?appid=CPCTDPIMPCAL)

| Parameter | Value |
| --- | --- |
| Configuration | L1-L2 |
| L1-L2 dielectric height (mm) | 0.0994 |
| L1-L2 dielectric constant | 3.55 |
| Soldermask substrate height (mm)  | 0.03048 |
| Soldermask trace height (mm) | 0.01524 |
| Soldermask dielectric constant | 3.8 |
| Trace thickness (mm) | 0.035 |
| Trace separation (mm) | 0.15 |
| Conductor spacing (mm) | 0.15 |
| Conductor width (mm) | 0.6 |

| Input parameter | Input value | Output parameter  | Output value  |
| --- | --- | --- | --- |
| Zdiff (Ω) | 85 | Trace width (mm)  | 0.1676 |
| Trace width (mm)  | 0.1549 | Zdiff (Ω) | 88.18 |

### Coplanar stripline single ended with ground plane
[Impedance calculator](https://impedance.app.protoexpress.com/?appid=CPSLSEIMPCAL)

| Parameter | Value |
| --- | --- |
| Configuration | L2-L3-L4  |
| L2-L3 dielectric height (mm)  | 0.0994 |
| L2-L3 dielectric constant | 3.55 |
| L3-L4 dielectric height (mm)  | 0.45 |
| L3-L4 dielectric constant | 4.4 |
| L3 Trace thickness (mm) | 0.01524 |
| Conductor spacing (mm) | 0.15 |
| Conductor width (mm) | 0.6 |
| Dielectric covering tracks | L2-L3 |

| Input parameter | Input value | Output parameter  | Output value  |
| --- | --- | --- | --- |
| Zdiff (Ω) | 42.5 | Trace width (mm)  | 0.174 |
| Trace width (mm)  | 0.1679 | Zdiff (Ω) | 43.27 |

### Coplanar soldermask coated microstrip singled ended with ground plane
[Impedance calculator](https://impedance.app.protoexpress.com/?appid=CPCTSEIMPCAL)

| Parameter | Value |
| --- | --- |
| Configuration | L1-L2 |
| L1-L2 dielectric height (mm) | 0.0994 |
| L1-L2 dielectric constant | 3.55 |
| Soldermask substrate height (mm)  | 0.03048 |
| Soldermask trace height (mm) | 0.01524 |
| Soldermask dielectric constant | 3.8 |
| Trace thickness (mm) | 0.035 |
| Conductor spacing (mm) | 0.15 |
| Conductor width (mm) | 0.6 |

| Input parameter | Input value | Output parameter  | Output value  |
| --- | --- | --- | --- |
| Zdiff (Ω) | 42.5 | Trace width (mm)  | 0.2 |
| Trace width (mm)  | 0.1971 | Zdiff (Ω) | 44.5 |

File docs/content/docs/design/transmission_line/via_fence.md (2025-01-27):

---
title: Via fence
prev: /docs/design/transmission_line/structures
next: /docs/design/transmission_line/via_jumps
weight: 2
params:
  icon: switch-horizontal
---

{{< responsive_image key="via_fence_diagram" >}}

## Crosstalk
- Improves impedance of coplanar ground guard trace by stitching it to a ground plane which improves E-field confinement.
- Additional ground vias improve E-field confinement.
- Both of these contribute to significantly reducing the inter-lane crosstalk.

## Spacing requirements
- If spacing is incorrect it can result in worse crosstalk since fence can behave like a resonant tank.
- For a given maximum frequency which needs to be blocked, the equation is given as follows.

{{< mathjax body >}}
\begin{align}
d_{spacing} &= \frac{\lambda_{min}}{8} \\
d_{spacing} &= \frac{c}{8 \sqrt{\epsilon_r} \times f_{max}}
\end{align}
{{< /mathjax >}}

For the best eye opening we should set the maximum frequency as the 5th harmonic of the PCIe fundemental frequency. The following spacing values are calculated with {{< mathjax >}} \epsilon_r = 4.1 {{< /mathjax >}} for FR4.

| Gen | {{< mathjax >}} f_{0} {{< /mathjax >}} (GHz) | {{< mathjax >}} f_{max} {{< /mathjax >}} (GHz) | {{< mathjax >}} d_{spacing} {{< /mathjax >}} (mm) |
| --- | --- | --- | --- |
| 1.0 | 1.25 | 6.25 | 2.96 |
| 2.0 | 2.5 | 12.5 | 1.48 |
| 3.0 | 4.0 | 20 | 0.93 |
| 4.0 | 8.0 | 40 | 0.46 |
| 5.0 | 16.0 | 80 | 0.23 |

## Manufacturing limitations
JLCPCB has manufacturing constraints that limits the geometry of our via fence. The following values are chosen to minimise the manufacturing cost and therefore may not be the best values we can choose.

| Parameter | Type | Value |
| --- | --- | --- |
| Via hole size | Minimum | 0.3mm |
| Via hole diameter | Minimum | 0.4mm |
| Via hole to different net distance | Minimum | 0.2mm |
| Via hole to hole spacing | Minimum | 0.2mm |

- Since we are targetting PCIe 4.0 our spacing requirement is 0.46mm and is within the manufacturing constraints.
- Our coplanar guard traces are placed 0.1mm away from signal traces so we only need 0.1mm of copper between the via and edge of coplanar guard trace.

## Resources
- {{< pdf_link key="north_dakota_university_via_fencing" >}}
- {{< website_link key="altium_via_stitching" >}}
- {{< website_link key="hackaday_rf_via_fence" >}}

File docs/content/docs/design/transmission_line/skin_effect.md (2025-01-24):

---
title: Skin effect
prev: /docs/design/transmission_line/via_jump
next: /docs/design/transmission_line/skew_requirements
weight: 4
params:
  icon: switch-horizontal
---

{{< responsive_image key="copper_roughness_skin_effect" >}}
- Skin effect is when the signal current is expelled to the surface of the conductor at high frequencies.
- With a rough copper finish, skin effect can result in higher trace impedance which can result in:
    - Signal loss through resistive losses.
    - Impedance mismatch and signal reflections.
- {{< website_link key="evident_scientific_copper_foil_surface_roughness" >}}

## Increasing trace width
- Use wider tranmission line signal traces to improve impedance and therefore signal integrity at higher frequencies.
- Comes at the cost of worse impedance matching at lower frequencies.
- Signal losses generally occur at higher frequencies (via jumps, tapered transitions, skin effect, insertion loss, dielectric loss).
- Therefore to achieve best performance over the entire bandwidth we should increase transmission line width to mitigate skin effect at higher frequencies.

## Copper finish
- PCB manufacturers have a variety of copper foil types to use if you need a smoother surface to avoid skin effect.
- {{< website_link key="altium_types_pcb_copper_foil" >}}
- {{< website_link key="altium_copper_roughness" >}}

| Type of copper foil | Description | Roughness |
| --- | --- | --- |
| Electrodeposited | Has a rougher surface on one side of the copper foil | Highest (above 1 um) |
| Reverse treated | Uses a surface treatment to reduce roughness | Moderate (0.5 um to 1.5 um) |
| Rolled-annealed | Has a smoother, denser surface from a rolling process | Low (0.25 to 0.5 um) |
| Ultra-low profile | Additional treatments are used to reduce roughness | Lowest (comparable to rolled annealed, but can be less than 0.3 um) |

- Unfortunately JLCPCB doesn't allow you to select the type of copper foil.

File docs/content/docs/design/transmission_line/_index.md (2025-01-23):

---
title: Transmission line
prev: /docs/design/flex_pcb
next: /docs/design/transmission_line/structures
weight: 6
params:
  icon: switch-horizontal
---

{{< toc >}}

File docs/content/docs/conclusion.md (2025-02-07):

---
title: Conclusion
prev: /docs/results/discussion
weight: 5
---

## DIY or Buy?
### DIY
<table>
  <thead>
    <tr>
      <th style="width: 50%">Advantages</th>
      <th style="width: 50%">Disadvantages</th>
    </tr>
  </thead>
  <tbody>
    <tr>
      <td style="vertical-align: text-top">
        <ul>
          <li>Can reach PCIe 3.0 speeds</li>
          <li>Can be designed to fit in any enclosure</li>
          <li>Cheaper per-unit cost</li>
          <li>Can be modified with different connector (MCIO)</li>
        </ul>
      </td>
      <td style="vertical-align: text-top">
        <ul>
          <li>Cannot reach PCIe 4.0 speeds</li>
          <li>Significant performance loss in synthetic benchmarks</li>
          <li>Expensive to manufacture when considering minimum order quantity of PCBs and components and soldering equipment</li>
          <li>Time consuming to manufacture especially including electrical testing</li>
          <li>Unclear if design needs overhaul to reach PCIe 4.0 without having equipment to test circuit at PCIe 4.0 speeds</li>
        </ul>
      </td>
    </tr>
  </tbody>
</table>

### Buy
<table>
  <thead>
    <tr>
      <th style="width: 50%">Advantages</th>
      <th style="width: 50%">Disadvantages</th>
    </tr>
  </thead>
  <tbody>
    <tr>
      <td style="vertical-align: text-top">
        <ul>
          <li>Can reach PCIe 4.0 speeds</li>
          <li>Beats PCIe 3.0 adapters in synthetic benchmarks</li>
          <li>Flexible micro-coax can be bent to fit most scenarios</li>
          <li>Cost is low considering performance and quality of adapter</li>
        </ul>
      </td>
      <td style="vertical-align: text-top">
        <ul>
          <li>Minimum length of adapter is 12cm which might make it too long even with bending</li>
        </ul>
      </td>
    </tr>
  </tbody>
</table>

### Conclusion
{{< responsive_image key="aliexpress_m2_oculink_pcie4_extension" style="width: 50%" >}}

- **Buying** the Aliexpress M.2 Oculink PCIe 4.0 adapter is the much more sensible option. 
- It works out of the box and requires minimal bending to fit into your enclosure.
- Also comes in a variety of lengths: ```[15cm, 20cm, 25cm, 30cm, 40cm]```.

## Future plans
- Check mini cool edge IO (MCIO) connector: 
    - Has a better official number of insertion cycles.
    - Cables are designed officially for PCIe 4.0 speeds.
- Fix performance problems and see if PCIe 4.0 speeds can be reached.
    - Redesign hatch plane and taper in flexible PCB design.
    - Use a low loss dielectric to reduce dielectric losses at PCIe 4.0 speeds.
    - Use smooth copper foil to reduce skin effect losses.
- Determine if there is a method to cheaply verify performance at PCIe 4.0 speeds.
    - High frequency oscilloscopes (>20GHz) required for PCIe testing are extremely expensive.
    - Most low cost (<$1000) and low frequency (<200MHz) oscilloscopes are not useful for validating PCIe peformance.

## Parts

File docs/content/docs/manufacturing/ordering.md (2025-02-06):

---
title: Ordering
prev: /docs/manufacturing
next: /docs/manufacturing/reflow_soldering
weight: 1
params:
  icon: cog
---

> [!NOTE]
> All prices are listed in $USD.

## JLCPCB
### Single board design
- 0.8mm thickness
- 4 layers
- 120mm by 80mm

| Part | Cost |
| --- | --- |
| Base | $2.00  |
| 4 layer 0.8mm stackup required HASL finish | $4.80 |
| 4 layer stackup above 50mmx50mm | $5.00 |
| Engineering cost of boards above 100mmx100m | $24.00 |
| **Total** | **$35.80** |

### Flexible PCB design
#### M.2 card
- 0.8mm thickness
- 4 layers
- 22mm x 42mm

| Part | Cost |
| --- | --- |
| Base | $2.00 |
| 4 layer 0.8mm stackup required HASL finish | $4.80 |
| **Total** | **$6.80** |

#### Oculink port board 
- 1.6mm thickness
- 4 layers
- 87mm x 21mm

| Part | Cost |
| --- | --- |
| Base | $2.00 |
| 4 layer stackup above 50mmx50mm | $5.00 |
| **Total** | **$7.00** |

#### Flexible PCB
- 0.11mm thickness
- 2 layers
- 83mm by 77mm

| Part | Cost |
| --- | --- |
| Base | $2.00 |
| **Total** | **$2.00** |

#### Total cost of all boards
| Board | Cost |
| --- | --- |
| M.2 card | $6.80 |
| Oculink port board | $7.00 |
| Flexible PCB | $2.00 |
| **Total** | **$15.80** |

## Components
The components for both the single board design and multi-board flexible PCB design are identical.

| Part | Unit Cost | Quantity | Total |
| --- | --- | --- | --- |
| Amphenol Oculink port <br>(G14A42121B12HR) | $3.50 | 1 | $3.50 |
| SOD52 Schottky diode | $0.25 | 1 | $0.25 |
| X7R 040 10nF MLCC | $0.05 | 5 | $0.25 |
| **Total** | | | **$4.00** |

- Components were ordered from [Mouser Australia](https://au.mouser.com/).
- There are minimum order quantities for the Oculink port connector which has a MOQ of 5.
- Price of extra components are not considered since we are just interested in cost of a completed M.2 to Oculink adapter board.

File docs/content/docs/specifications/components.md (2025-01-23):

---
title: M.2 to Oculink
prev: /docs/specifications/pcie_specification
next: /docs/design
weight: 2
params:
  icon: chip
---

## M.2 card
- Usually used for M.2 SSDs in laptop or desktop motherboards.
- Pins follow the PCIe specification for x4 lanes.

{{< responsive_image key="m2_card_size" style="width: 75%" >}}
{{< responsive_image key="m2_connector_pinout_table" style="width: 50%" >}}

## Oculink port
- Follows the SFF-9402 specification which is compatible with PCIe
- {{< pdf_link key="sff_9402_specification" >}}
- Female port is rated for 10000 insertion cycles.
- Male cable is rated at a minimum of 50.
- Compatible with the PCIe specification for x4 or x8 lanes.
- Wider x8 lane variant is not as useful since no M.2 slot as of yet supports PCIe x8 lanes.
- {{< pdf_link key="amphenol_oculink_port_datasheet" >}}

{{< responsive_image key="amphenol_oculink_port" style="width: 50%" >}}
{{< responsive_image key="amphenol_oculink_port_pinout_table" >}}

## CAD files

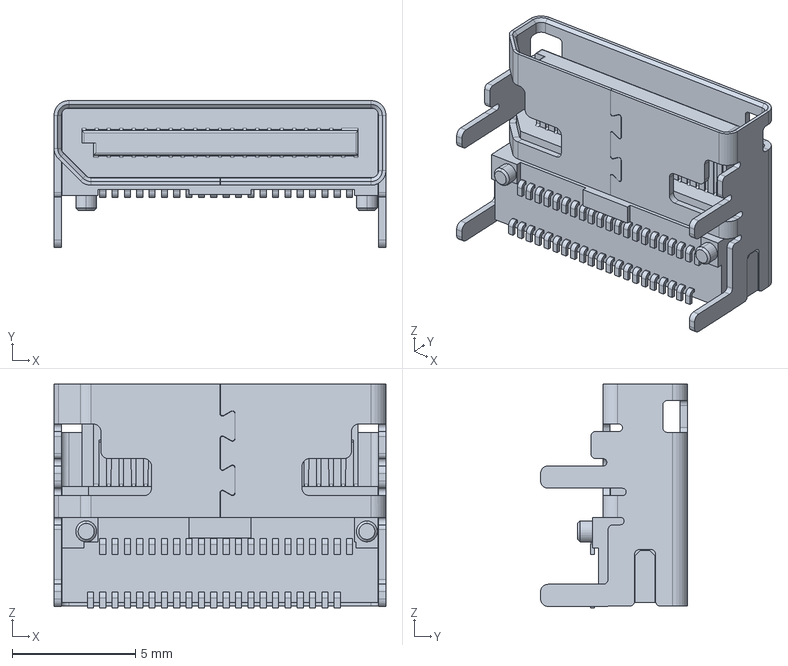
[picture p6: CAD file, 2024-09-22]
kicad/custom_components/amphenol_oculink_models/G14A42121B12HR.step
13.4 x 5.95 x 9.07 mm

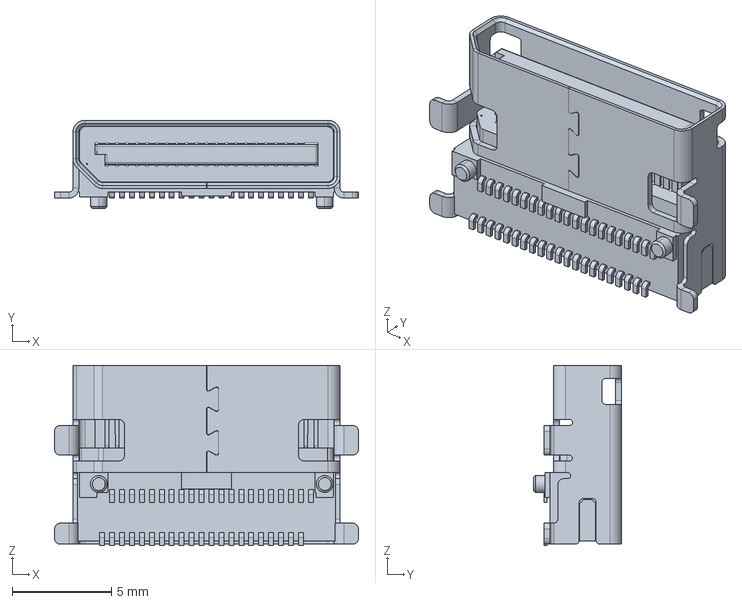
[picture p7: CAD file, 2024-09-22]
kicad/custom_components/amphenol_oculink_models/G14A421211112HR.step
15.3 x 4.45 x 9.07 mm

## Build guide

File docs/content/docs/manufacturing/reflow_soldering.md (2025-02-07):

---
title: Reflow soldering
prev: /docs/manufacturing/ordering
next: /docs/manufacturing/electrical_testing
weight: 2
params:
  icon: fire
---

## Equipment
- Reflow soldering plate.
- Soldering iron with a conical tip.
- Magnifying glass.
- Isopropyl alcohol.
- Metal tweezers.

{{< responsive_image key="mechanic_ix5_reflow" style="width: 50%" >}}
{{< responsive_image key="ts100_soldering_iron" style="width: 50%" >}}

## Reflow profile
1. Set a target temperature on the Mechanic IX5 reflow plate.
2. Activate the reflow process which will increase the temperate by 1°C each second until target temperature is reached.
3. Once the reflow temperature is reached let it remain at this temperature until reflow has finished.
4. Allow the PCB to cool which decrease temperature by 1°C each second until it is cool enough to handle.

{{< responsive_image key="reflow_profile" >}}

The Mechanic IX5 can be used to follow an arbitrary reflow profile (including the shown trapezoidal or delta types). The delta type reflow profile is sufficient for the Oculink port.

## Instructions
### Reflow soldering components
1. Apply stencil for Oculink connector and capacitors to spread solder paste.
2. Visually check to make sure there are no bridges or missing solder paste on SMD pads.
3. Place oculink port carefully onto SMD pads as to align them correctly.
4. Follow reflow profile with a target temperature of 220°C and keep it there for 60 seconds before ramping it down.
5. Visually confirm that there are no solder bridges on visible connections.
6. Validate that there are no shorts or bad connections following [electrical testing]({{< abs_url link="docs/manufacturing/electrical_testing" >}}).
    - Due to simple design of circuit the complications should only occur with the Oculink port itself.
    - Here excessive or insufficient solder paste can result in short circuits or a missing electrical connection.
    - Repeat steps 1 to 5 until the Oculink port is soldered correctly.

For the flexible PCB design continue to the following instructions below.

### Soldering flex connector
This process is only required for the two part board which is connected over the flexible PCB.

1. Perform reflow soldering of components for each of the two boards as described above.
2. Tin the SMD connection pads on both the flexible PCB and M2 card and Oculink port board.
    - Make sure that there is a minimal amount of solder to prevent shorts when reflow soldering connector.
    - Check to see if amount of solder has same height across all pads. If there isn't remove it until it is level.
3. Focus on the Oculink port board first and preheat it to 140°C.
4. Preheat the soldering iron with the conical tip to 280°C.
5. Using metal tweezers carefully position the flexible connector to align with the SMD pads.
    - Add flux to the flexible connector and board will help keep the connector in place once aligned.
    - Do this under a magnifying glass with mechanical helper hands.
6. Using the soldering iron solder the ground SMD pads after alignment.
    - Be careful to not misalign the connector.
    - Increase the preheating temperature of the board to 150°C or above if soldering isn't occuring.
    - Avoid preheating the board to too high of a temperature otherwise solder may become molten and components and Oculink port can be knocked off.
    - Avoid keeping the board preheated for too long otherwise PCB will discolour.
    - Make sure that you have soldered enough of the ground pads to keep the connector in place.
7. Let the Oculink port board cool down and check that flexible PCB is **mechanically** secure enough to move assembly around.
    - At this step there is no sound electrical connection between the board and flexible PCB.
    - We only need it to be mechanically secure so we can perform the full reflow step under mechanical pressure.
8. Place a weight on top of the flexible PCB connection to equally apply force on the SMD pads.
    - The weight should cover the entire flexible PCB connection pads.
    - The weight should not melt at the reflow temperature of 220°C.
    - The weight should be secure and stationary during reflow process.
9. Perform reflow soldering of the flexible PCB connection while the connections are under constant force.
    - Since there are no spring contacts, the z-height tolerance of the connection is very low.
    - To guarantee a good electrical connection the reflow process has to occur while the pads are under compressive pressure.
    - Be careful not to disturb the existing connections such as the Oculink port and capacitors.
10. Perform electrical tests as described in [electrical testing]({{< abs_url link="docs/manufacturing/electrical_testing" >}}).
    - This is done to make sure shorts don't occur due at the flexible PCB connection with the Oculink port board.
    - If shorts do occur at this step repeat steps 1 to 10 with less solder on the pads.
    - If these is a missing electrical connection make sure that sufficient pressure has been applied during reflow.
11. Repeat setps 1 to 10 for the M.2 card.

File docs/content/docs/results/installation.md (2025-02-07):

---
title: Installation
prev: /docs/results/
next: /docs/results/synthetic_benchmarks
weight: 1
params:
  icon: camera
---

## Single board adapter
{{< responsive_image key="laptop_photo_single_board" style="width: 50%" >}}

- Doesn't require routing of cables under M.2 slot.
- Port was positioned differently in later designs, but Oculink connection can still be made by bending the board slightly.

## Flexible PCB multi board adapter
{{< responsive_image key="laptop_photo_flex_pcb" style="width: 50%" >}}
{{< responsive_image key="laptop_photo_flex_pcb_with_m2" style="width: 50%" >}}

- M.2 2280 SSD is removed so flexible PCB can be routed under it.
- M.2 card and Oculink port board are screwed.
- Oculink port board can be positioned to perfectly match the routed Oculink port hole in the laptop chassis.
- M.2 2280 SSD is installed ontop of the flexible PCB.

## Aliexpress PCIe 4.0 adapter
{{< responsive_image key="aliexpress_m2_oculink_pcie4_extension" style="width: 50%" >}}
{{< responsive_image key="laptop_photo_aliexpress" style="width: 50%" >}}

- Aliexpress adapter extension is made of micro-coaxial cable.
- These can be bent to fit inside the laptop chassis and routed underneath the M.2 2280 SSD.

## Oculink port
{{< responsive_image key="laptop_photo_side_port" style="width: 50%" >}}

- Oculink port hole was created by drilling with tungsten drill bits.
- Multiple drill holes were used to create a rough opening and then sanded down into the correct shape.

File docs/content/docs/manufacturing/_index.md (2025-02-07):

---
title: Manufacturing
prev: /docs/design/open_ems/taper
next: /docs/manufacturing/ordering
weight: 3
params:
    icon: cog
---

{{< toc >}}

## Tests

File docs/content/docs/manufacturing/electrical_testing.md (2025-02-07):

---
title: Electrical testing
prev: /docs/manufacturing/reflow_soldering
next: /docs/results
weight: 3
params:
  icon: badge-check
---

## Single board validation
- Oculink port has a small pitch of 0.2mm which can easily create solder bridges.
- Validate this by connecting the Oculink port to the unpowered PCIe eGPU board.
- Refer to [M.2 pinout]({{< abs_url link="docs/specifications/components/" >}}) and [PCIe pinout]({{< abs_url link="docs/specifications/pcie_specification/" >}}) for the electrical connections to test for.
- Depending on the design the PCIe lanes may be connected in opposite polarity and/or in opposite orders.
- Check for short circuits and bad connections.
- Use a magnifying glass to position multimeter probes onto the exposed electrical contacts.

## Flexible PCB multi board design
Validation of flexible PCB design will be done in three passes.

{{< responsive_image key="kicad_flex_connector_render" >}}

### 1. Oculink port board
- After Oculink port has been soldered to PCB perform similar checks as with the single board design.
- Instead of using the M.2 connection use the exposed flexible PCB SMD pads to test for shorts or bad electrical connections.

### 2. Flexible PCB to Oculink port
- After soldering flexible PCB to Oculink port board perform the same check but with the exposed flexible PCB pads on the M.2 side of the flexible PCB.
- Perform visual checks of the flexible PCB at the soldered connection. Since the polyimide is translucent it is possible to detect solder bridges.
- If there are any shorts or bad connections they are likely isolated to the flexible PCB connection since we have already verified the Oculink port itself.

### 3. Flexible PCB to M.2 port
- After soldering flexible PCB to M.2 card perform same check as with the single board design.
- Perform visual checks of the flexible PCB at the soldered connection. Since the polyimide is translucent it is possible to detect solder bridges.
- If there are any shorts or bad connections they are likely isolated to the flexible PCB connection on the M.2 card side.
- Due to steps 1 and 2 the Oculink port and flexible PCB connection on the Oculink board side are verified.

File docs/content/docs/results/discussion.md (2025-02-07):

---
title: Discussion
prev: /docs/results/synthetic_benchmarks
next: /docs/conclusion
weight: 3
---

## Display setup
```mermaid
sequenceDiagram;
    participant eGPU
    participant CPU
    participant USB 4 dock
    participant 1080p monitor
    CPU->>eGPU: Oculink PCIe TX
    eGPU->>CPU: Oculink PCIe RX
    CPU->>USB 4 dock: 40Gb/s USB 4 cable
    USB 4 dock->>1080p monitor: HDMI cable
```

- Benchmark output display is connected to a USB 4 dock (40Gb/s) and has a resolution of 1080p.
- This means Oculink PCIe connection has to be stable in both the transmit and receive direction.
- When eGPU data comes back to CPU it actually goes through the integrated AMD 680m based on copy activity in task manager.

## Flexible PCB and single board design
{{< carousel key="custom_adapters" >}}
<div class="carousel-item">
  <div class="responsive-image">
    
  </div>
</div>
<div class="carousel-item">
  <div class="responsive-image">
    
  </div>
</div>
{{< /carousel >}}

- Both the flexible PCB multi-board design and single board design achieved PCIe 3.0 speeds.
- Their results across all synthetic benchmarks were identical.
- PCIe 3.0 connection was stable and bandwidth reached theoretical values.
- PCIe 4.0 could not be achieved at all.

## Aliexpress PCIe 4.0 adapters
{{< carousel key="aliexpress_adapters" >}}
<div class="carousel-item">
  <div class="responsive-image">
    
  </div>
</div>
<div class="carousel-item">
  <div class="responsive-image">
    
  </div>
</div>
{{< /carousel >}}

- Both the adapters that came with the Adtlink eGPU and the silver plated 12cm adapter reached PCIe 4.0 speeds.
- PCIe 4.0 connection was stable and bandwidth reached theoretical values.
- Performance uplift from PCIe 3.0 to PCIe 4.0 in this setup is significant.
- Bandwidth limit from eGPU to CPU limits the number of frames that can be sent to display.

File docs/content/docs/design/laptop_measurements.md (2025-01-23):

---
title: Laptop measurements
prev: /docs/design/reference_designs
next: /docs/design/kicad_jlcpcb
weight: 2
params:
  icon: color-swatch
---

## Measurement and modelling
{{< responsive_image key="lenovo_16arp8_dimensions" >}}
{{< responsive_image key="lenovo_16arp8_3d_model" >}}

- Modelling was done from a sparse set of measurements.
- After modelling was done arbitrary measurements of any feature could be done.
- Easier than measuring every possible dimension when needed.

## Planning
- Longer M.2 2280 slot is used for high capacity SSD.
- Shorter M.2 2242 slot is available but in a less convenient location.
- Left speaker can be removed to make room for Oculink port.
- M.2 2242 slot has 1mm of clearance for bottom side passive components.
- **Option 1**: Very narrow 12mm gap between M.2 2280 connector and internal display connector for single board design for side Oculink port.
- **Option 2**: Vertical space underneath M.2 2280 slot for routing with a flex pcb design that has a side Oculink port.
- **Option 3**: Use vertical Oculink adapter and have port on bottom instead of side of laptop.

{{< responsive_image key="nfhk_vertical_m2_to_oculink_adapter" style="width: 75%">}}

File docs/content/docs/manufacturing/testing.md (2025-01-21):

---
title: Testing
prev: /docs/manufacturing/reflow_soldering
next: /docs/results
weight: 3
---

## Checking for shorts
- Oculink port after reflow can be shorted due to excess or smeared solder paste resulting in bridges between fine pitch pins
    - Can redo reflow as many times until short is gone
- For flex pcb shorts can occur between fine pitch SMD pads of FFC connector
    - Visual inspection through transparent FFC can reveal where shorts are

## Checking flex pcb during assembly
- For flex pcb bad connections can be checked partially through assembly
- Begin by soldering FFC to M.2 card
    - Check for shorts and bad connections between M.2 edge connector and end of FFC cable
- Begin reflowing oculink port to separate PCB
    - Check for shorts on exposed connector pads
- Bad connection or short will likely be located at FFC to oculink board connection

## Checking assembled board 
- Connect oculink adapter to eGPU board
- The PCIe connector on the eGPU board can be used to check for continuity and shorts
    - Refer to following schematic for pin out of PCIe connector
- Use m.2 edge connector as other side of connection
    - Refer to pinout for m.2 connector

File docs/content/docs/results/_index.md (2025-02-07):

---
title: Results
prev: /docs/manufacturing/electrical_testing
next: /docs/results/installation
weight: 4
params:
    icon: calculator
---

{{< toc >}}

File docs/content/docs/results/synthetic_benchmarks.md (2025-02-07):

---
title: Synthetic benchmarks
prev: /docs/results/installation
next: /docs/results/discussion
weight: 2
params:
  icon: calculator
---

## Aida64
{{< aida64_table >}}

## 3DMark
{{< benchmark_table key="3d_mark" >}}
{{< benchmark_carousel key="3d_mark" >}}

## Unigine
{{< benchmark_table key="unigine" >}}
{{< benchmark_carousel key="unigine" >}}

## Furmark 2
{{< benchmark_table key="furmark2" >}}
{{< benchmark_carousel key="furmark2" >}}

## GPU-Z
{{< gpuz_images >}}

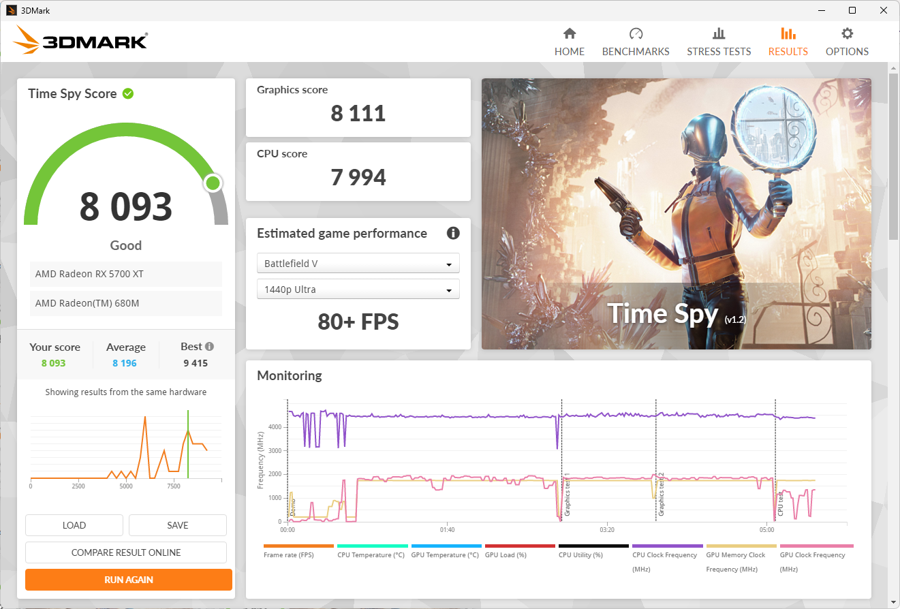
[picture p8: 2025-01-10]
docs/static/images/benchmarks/3dmark_time_spy_flex_pcb.png

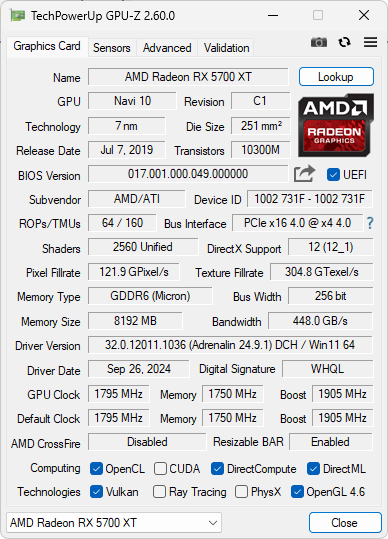
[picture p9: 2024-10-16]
docs/static/images/benchmarks/gpuz_amd_5700xt.png

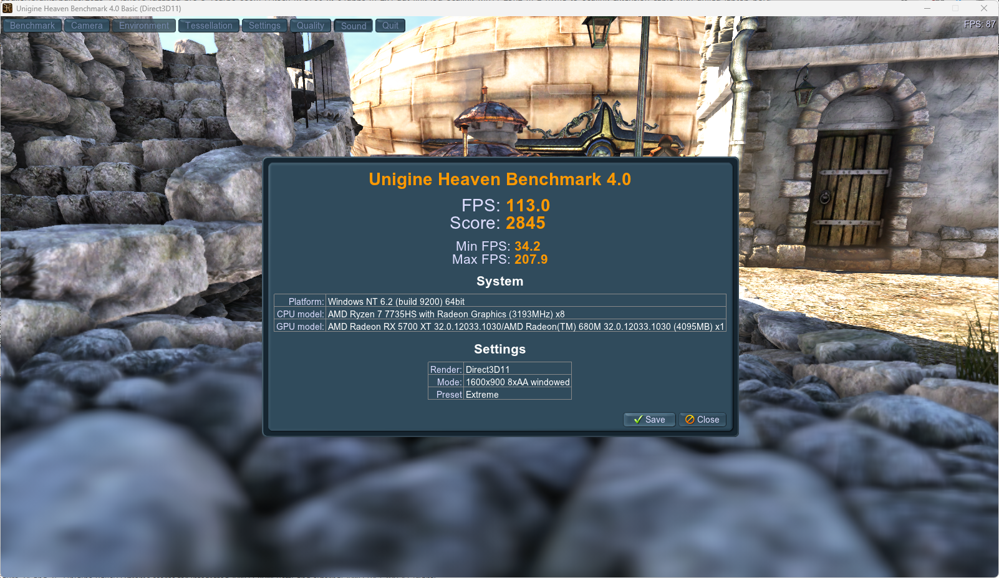
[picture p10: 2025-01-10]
docs/static/images/benchmarks/unigine_heaven_extreme_flex_pcb.png

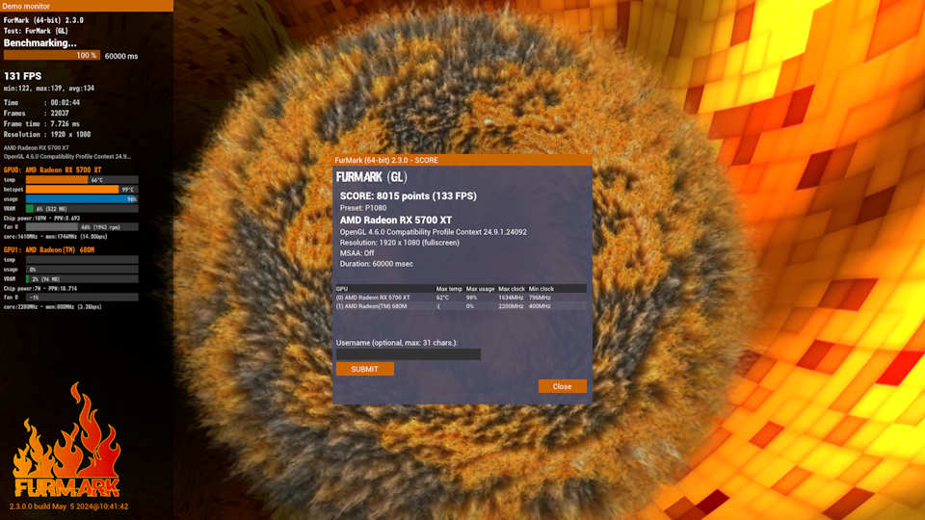
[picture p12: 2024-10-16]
docs/static/images/benchmarks/furmark2_donut_gl_amd_5700xt.png

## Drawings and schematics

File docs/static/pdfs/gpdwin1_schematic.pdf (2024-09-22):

### +V3P3A_SSD_CONN

### +V3P3A_OCULINK_OUT

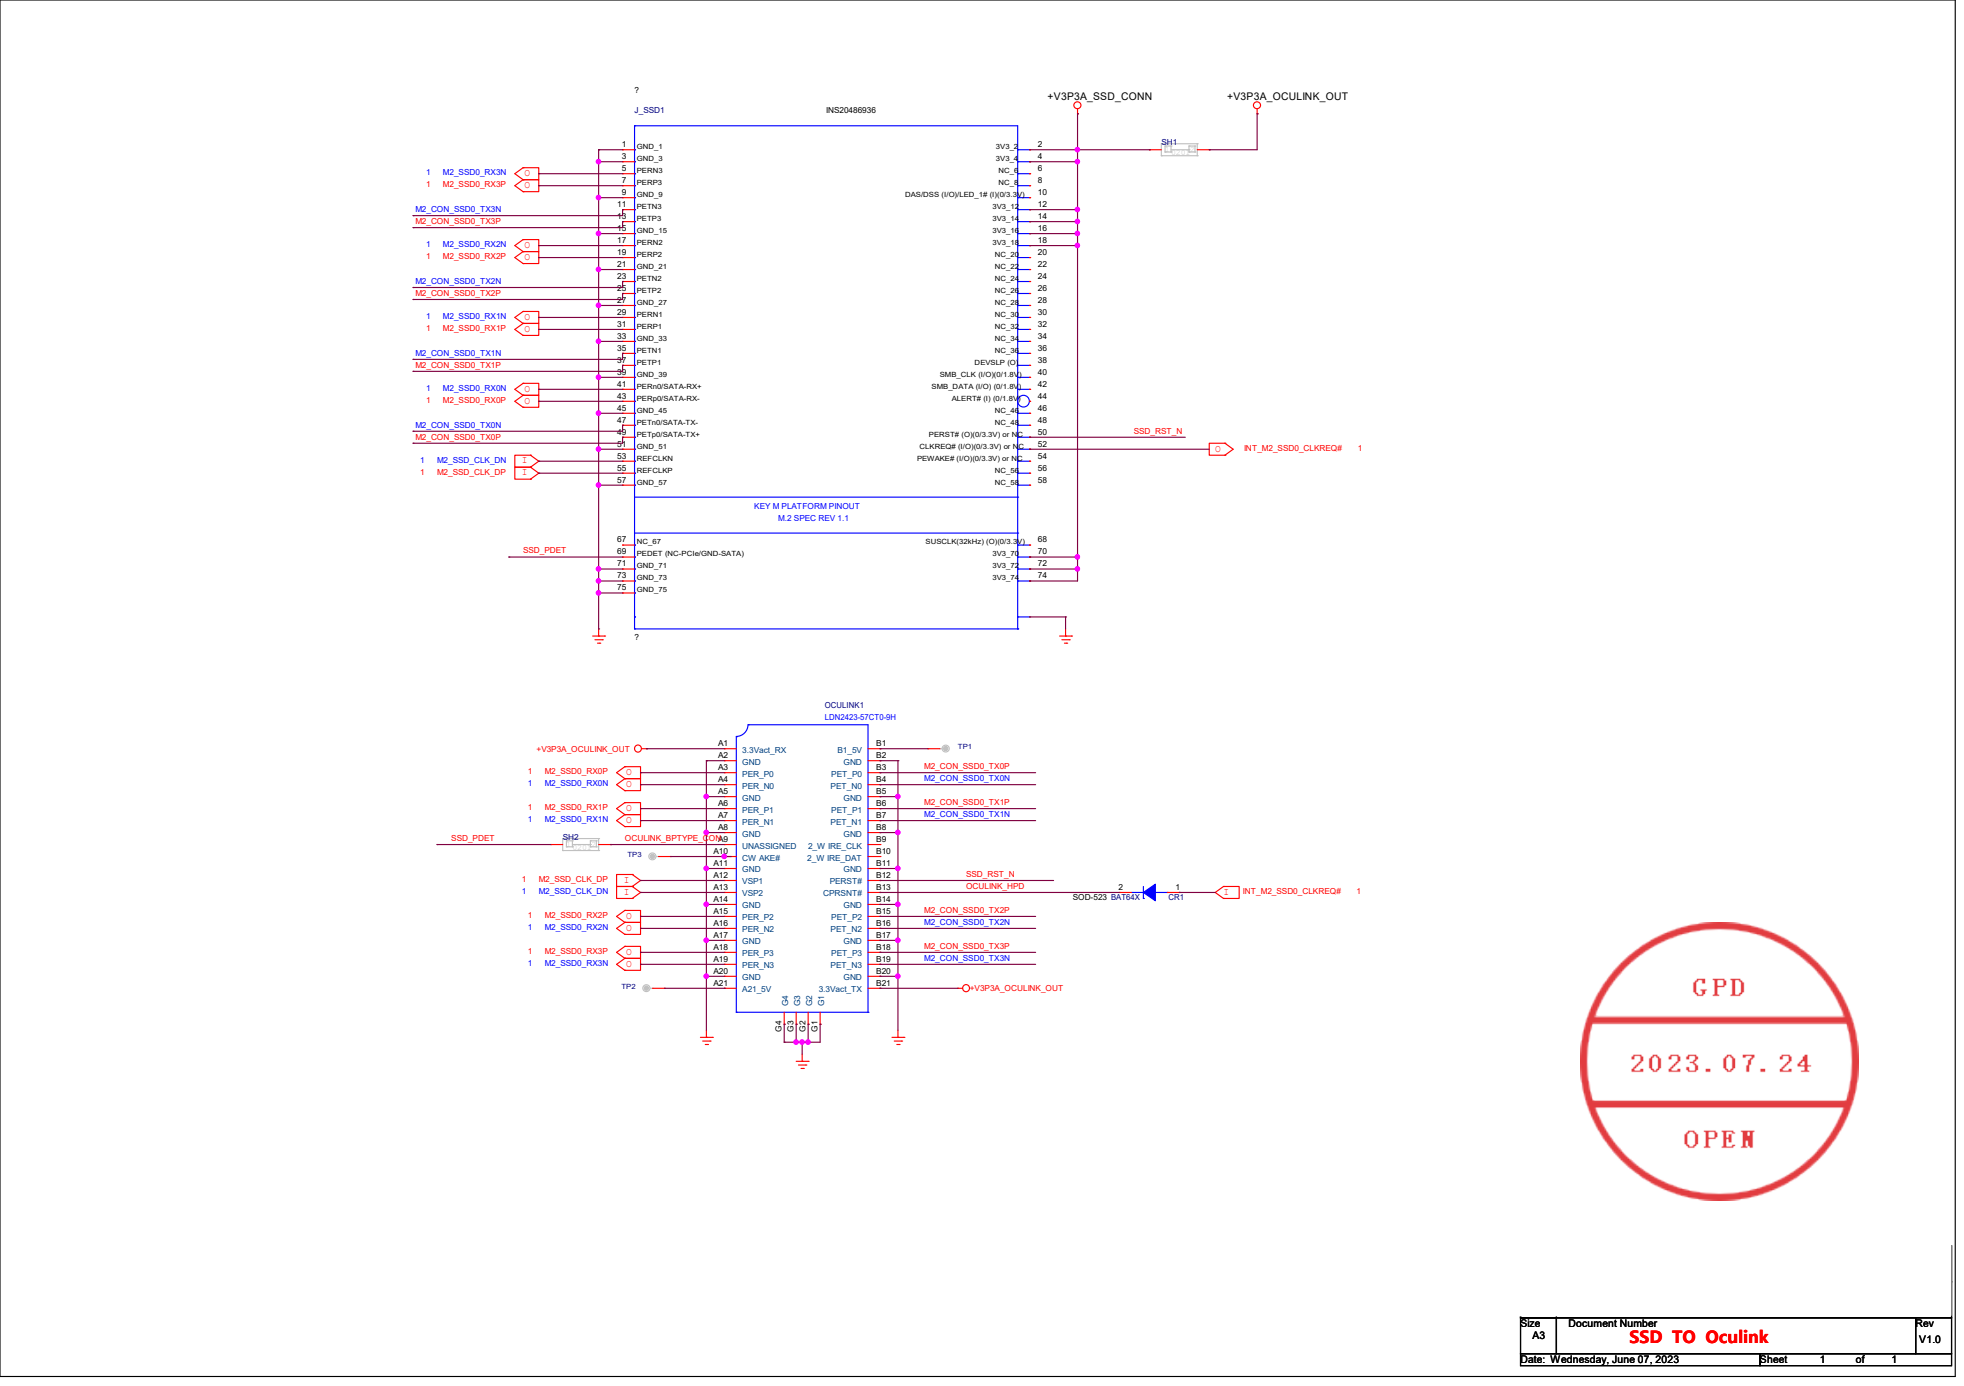
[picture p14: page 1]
+V3P3A_OCULINK_OUT; INT_M2_SSD0_CLKREQ#; M2_SSD0_RX3N; M2_SSD0_RX3P; M2_SSD0_RX2P; M2_SSD0_RX2N; M2_SSD0_RX1P; M2_SSD0_RX1N; M2_SSD_CLK_DN; M2_SSD_CLK_DP; M2_SSD0_RX0P; M2_SSD0_RX0N; Size; Document Number; Rev Date:; Sheet; SSD TO Oculink; V1.0 A3 Wednesday, June 07, 2023; 1 Size; SOD-523 BAT64X; INS20486936; J_SSD1 1; GND_1; GND_3; PERN3; PERP3; GND_9; DAS/DSS (I/O)/LED_1# (I)(0/3.3V); PETN3; PETP3; GND_15; PERN2; PERP2; GND_21; PETN2; PETP2; GND_27; PERN1; PERP1; GND_33; PETN1; PETP1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

KEY M PLATFORM PINOUT
M.2 SPEC REV 1.1

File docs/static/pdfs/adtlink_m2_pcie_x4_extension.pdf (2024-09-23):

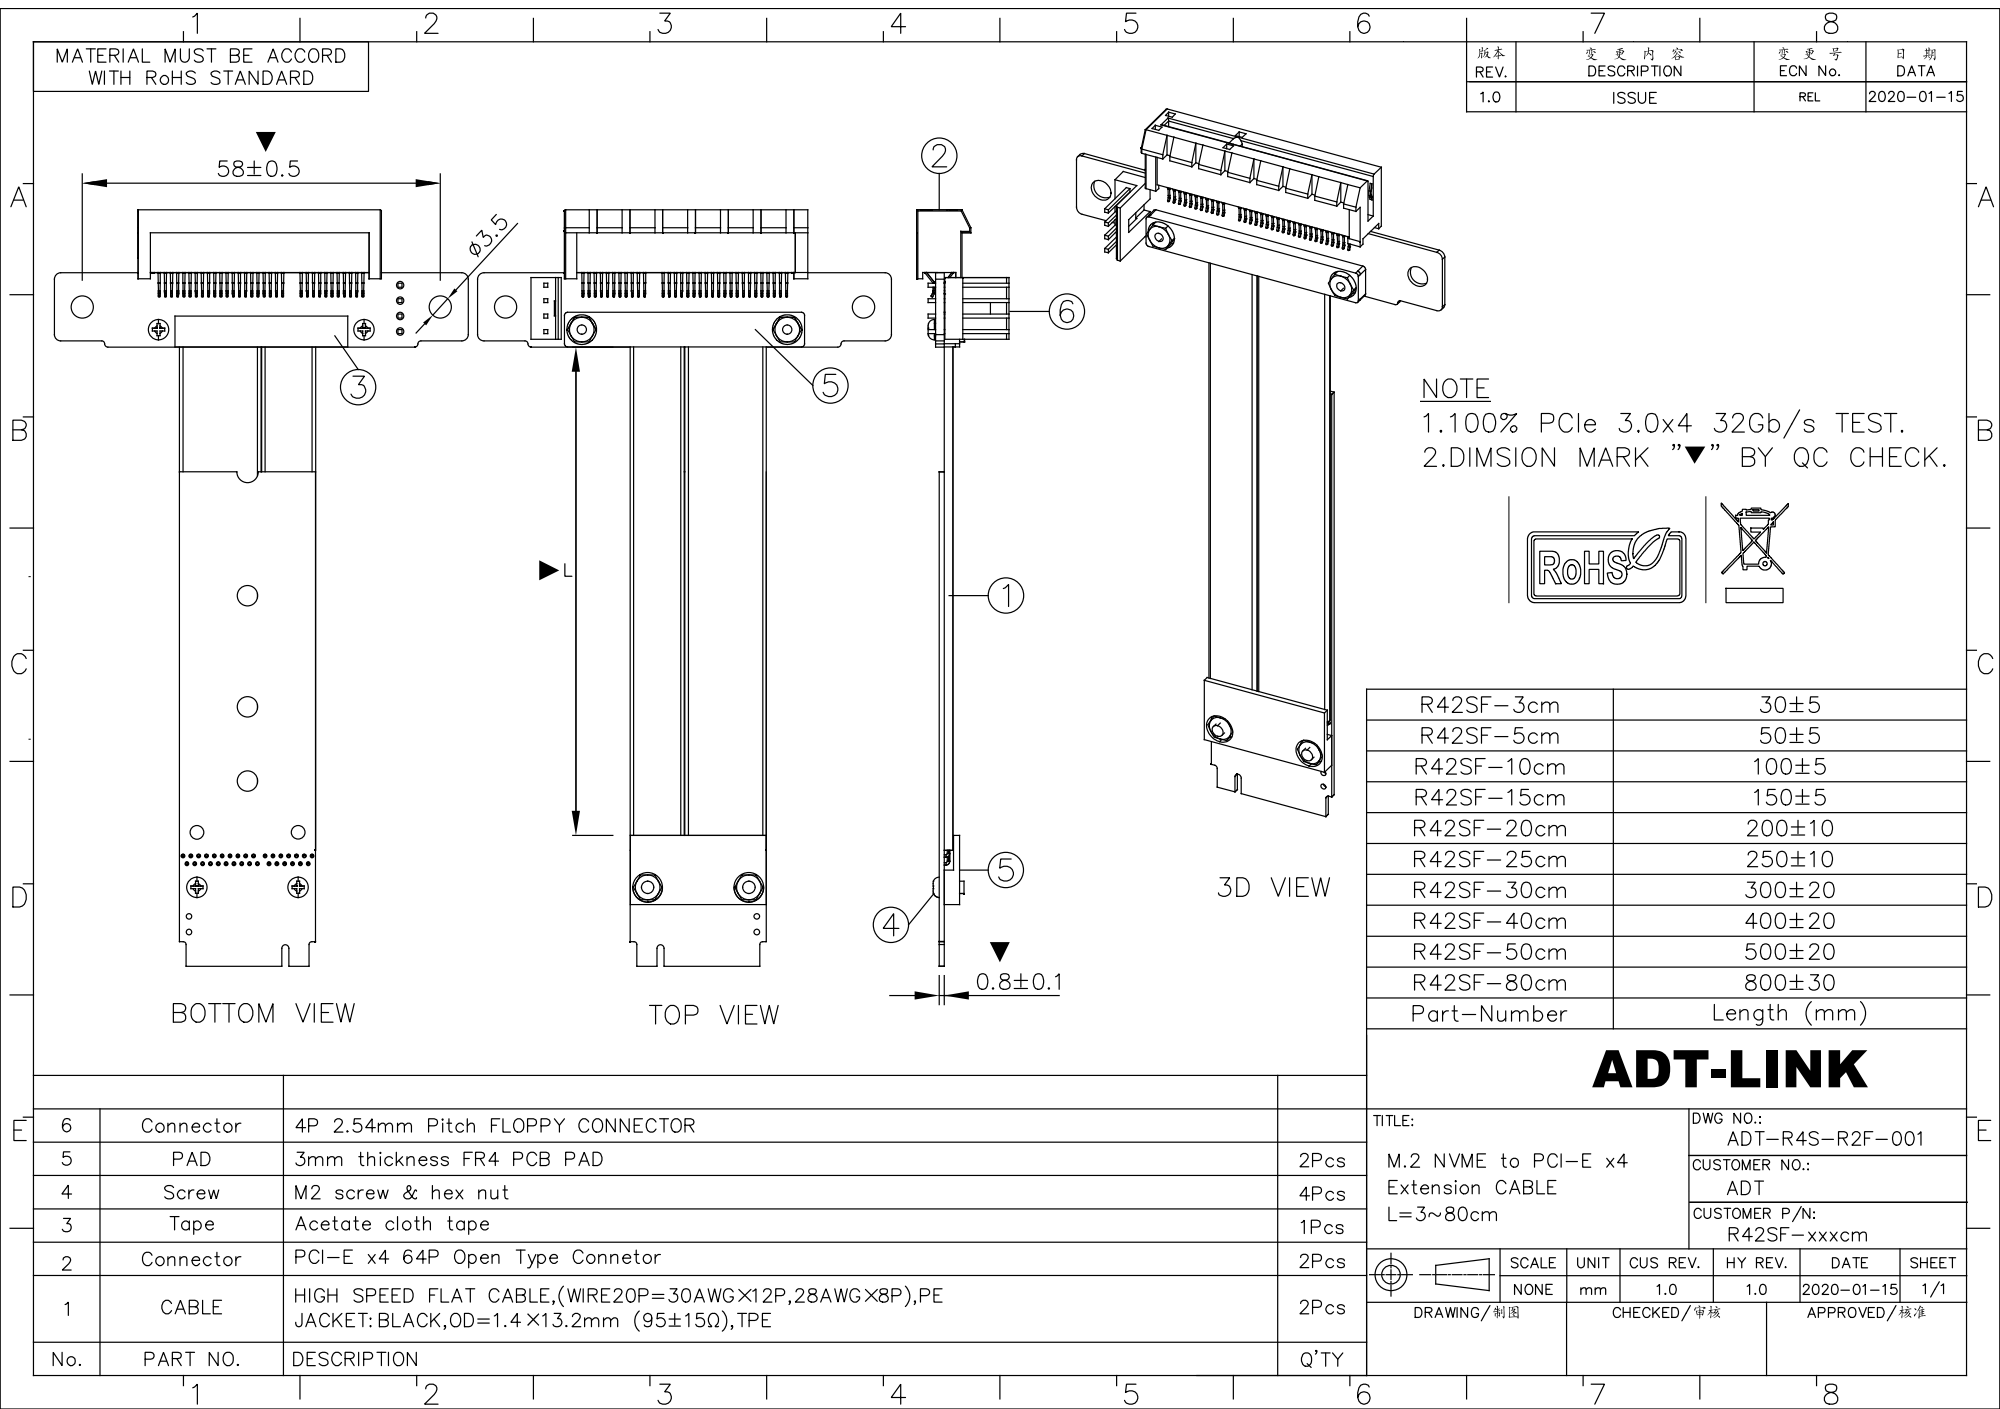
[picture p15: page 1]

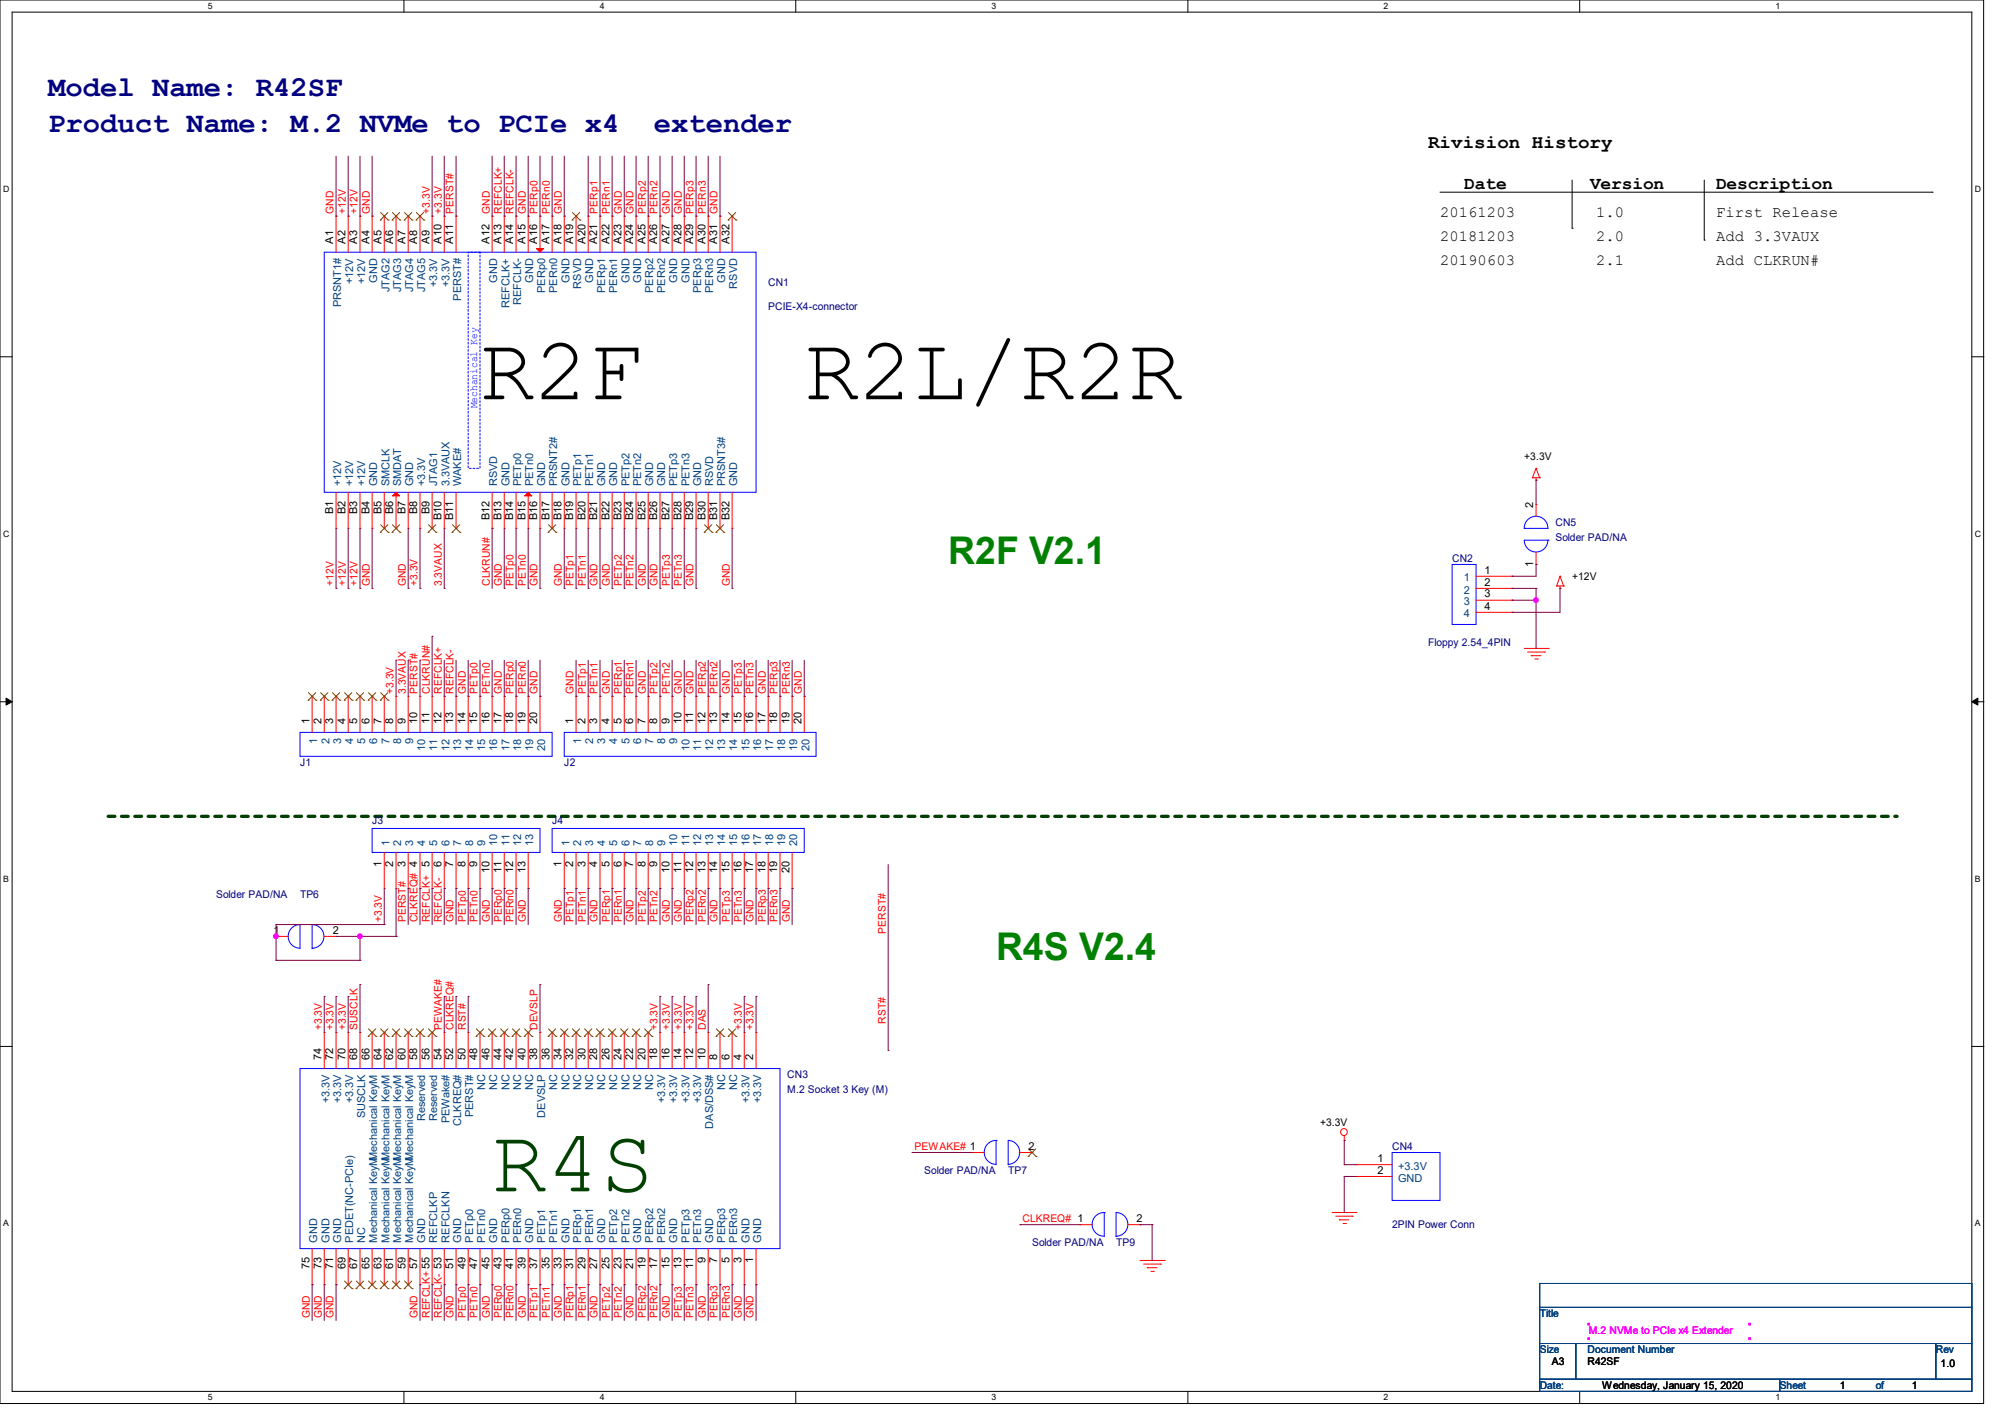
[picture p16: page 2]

Model Name: R42SF
Product Name: M.2 NVMe to PCIe x4 extender

9 13 13 Mechanical Key CN1 PCIE-X4-connector +12V B3 GND B4 SMCLK B5 SMDAT B6 GND B7 +3.3V B8 JTAG1 B9 WAKE# B11 PETn0 B15 GND B16 PRSNT2# B17 GND B18 +12V A2 GND A4 JTAG2 A5 JTAG3 A6 JTAG4 A7 JTAG5 A8 +3.3V A10 REFCLK- A14 GND A15 PERp0 A16 PERn0 A17 GND A18 +12V B1 +12V B2 PRSNT1# A1 +12V A3 +3.3V A9 3.3VAUX B10 PETp0 B14 RSVD B12 GND B13 PERST# A11 GND A12 PETp1 B19 PETn1 B20 GND B21 GND B22 PETp2 B23 PETn2 B24 GND B25 GND B26 PETp3 B27 PETn3 B28 GND B29 RSVD B30 PRSNT3# B31 GND B32 RSVD A19 REFCLK+ A13 GND A20 PERp1 A21 PERn1 A22 GND A23 GND A24 PERp2 A25 PERn2 A26 GND A27 GND A28 PERp3 A29 PERn3 A30 GND A31 RSVD A32 CN3 M.2 Socket 3 Key (M) PETn0 47 PETp0 49 GND 51 PERn0 41 PERp0 43 GND 45 GND 39 PETp1 37 PETn1 35 GND 33 PERp1 31 PERn1 29 PETp2 25 PETn2 23 GND 21 PERp2 19 PERn2 17 GND 15 PETp3 13 PETn3 11 GND

4 +3.3V 74 +3.3V 72 +3.3V 70 SUSCLK 68 Mechanical KeyM 66 Mechanical KeyM 64 Mechanical KeyM 62 Mechanical KeyM 60 Reserved 58 Reserved 56 PEWake# 54 GND 75 GND 73 GND 71 PEDET(NC-PCIe) 69 NC 67 Mechanical KeyM 65 Mechanical KeyM 63 Mechanical KeyM 61 Mechanical KeyM 59 GND 57 REFCLKP 55 REFCLKN 53 GND 27

1 CLKREQ# 52 PERST# 50 NC 48 NC 46 NC 44 NC 42 NC 40 DEVSLP 38 NC 36 NC

8 DAS/DSS# 10 +3.3V 12 +3.3V 14 +3.3V 16 +3.3V 18 NC 34 NC 32 NC 30 NC 28 NC 26 NC 24 NC 22 NC 20 PERn3

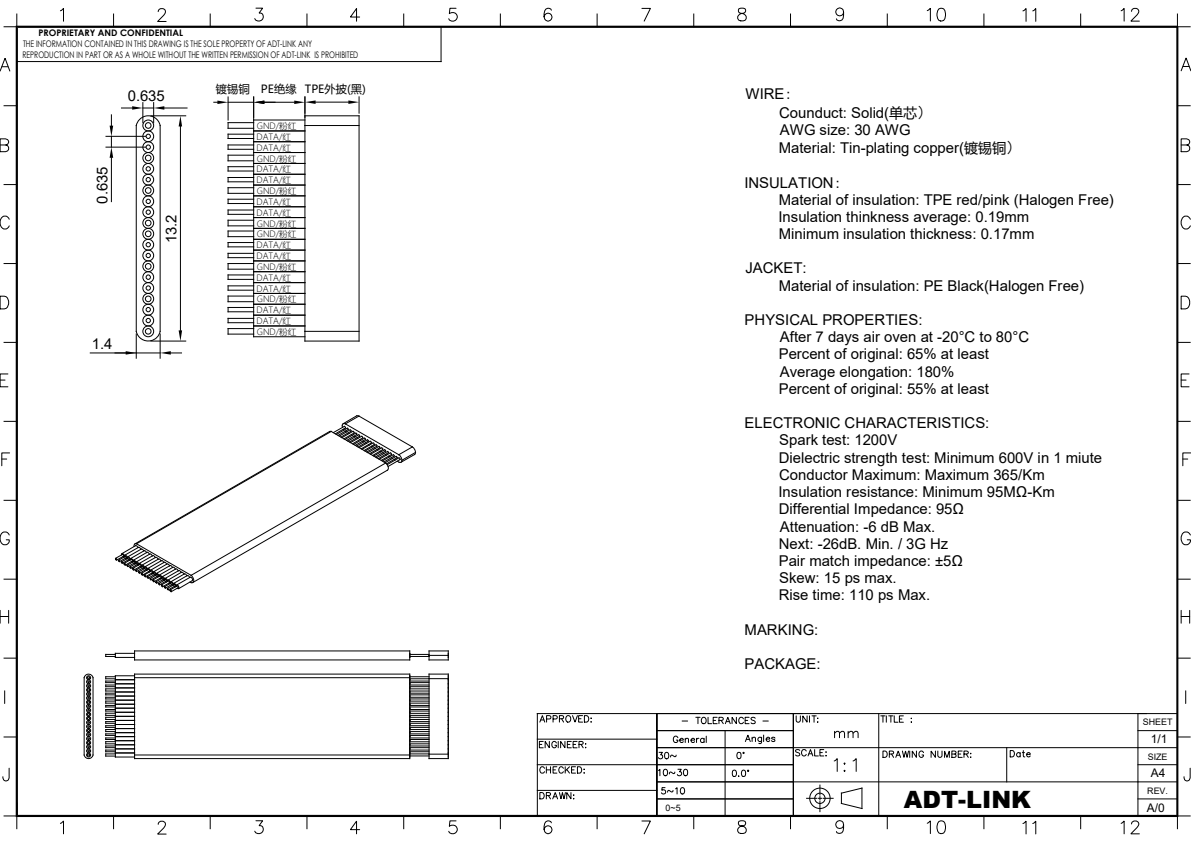
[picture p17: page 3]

PROPRIETARY AND CONFIDENTIAL
THE INFORMATION CONTAINED IN THIS DRAWING IS THE SOLE PROPERTY OF ADT-LINK ANY
REPRODUCTION IN PART OR AS A WHOLE WITHOUT THE WRITTEN PERMISSION OF ADT-LINK IS PROHIBITED

WIRE：
Counduct: Solid(单芯
AWG size: 30 AWG
Material: Tin-plating copper(镀锡铜

INSULATION：
Material of insulation: TPE red/pink (Halogen Free)
Insulation thinkness average: 0.19mm
Minimum insulation thickness: 0.17mm

JACKET:
Material of insulation: PE Black(Halogen Free)

PHYSICAL PROPERTIES:
After 7 days air oven at -20°C to 80°C
Percent of original: 65% at least
Average elongation: 180%
Percent of original: 55% at least

ELECTRONIC CHARACTERISTICS:
Spark test: 1200V
Dielectric strength test: Minimum 600V in 1 miute
Conductor Maximum: Maximum 365/Km
Insulation resistance: Minimum 95MΩ-Km
Differential Impedance: 95Ω
Attenuation: -6 dB Max.
Next: -26dB. Min. / 3G Hz
Pair match impedance: ±5Ω
Skew: 15 ps max.
Rise time: 110 ps Max.

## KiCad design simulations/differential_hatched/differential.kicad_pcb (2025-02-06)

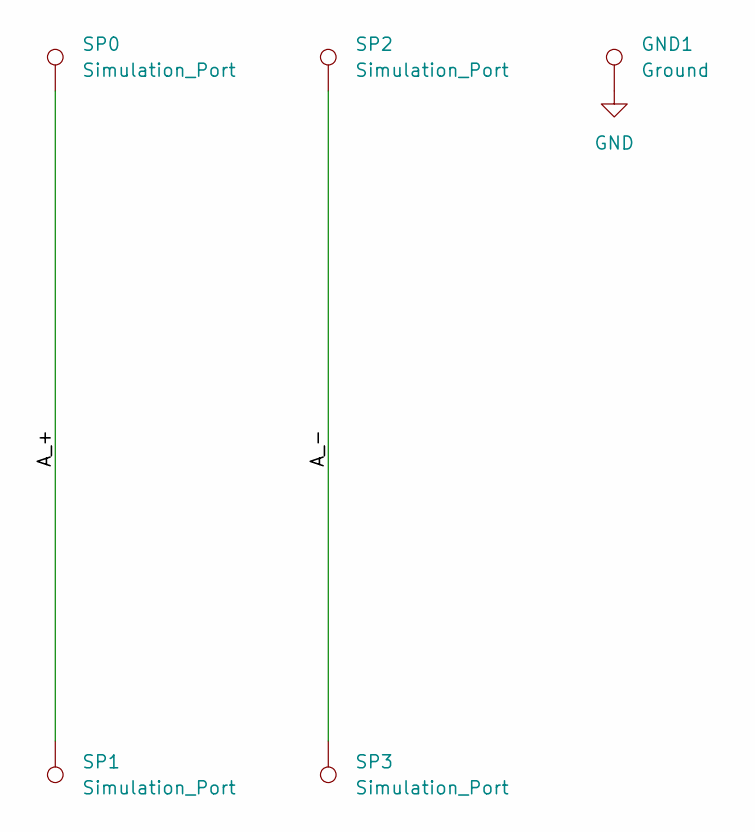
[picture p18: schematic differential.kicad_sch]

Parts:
GND1: Ground; pad_0.1mm
SP0, SP1, SP2, SP3: Simulation_Port; pad_0.15mm

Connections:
/A_+: SP0.1, SP1.1
/A_-: SP2.1, SP3.1
GND: GND1.1

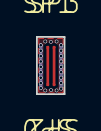
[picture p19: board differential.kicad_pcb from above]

Board: 2 copper layers, 1.5 x 3.2 mm, 5 parts (1 on the bottom side), 2 nets.

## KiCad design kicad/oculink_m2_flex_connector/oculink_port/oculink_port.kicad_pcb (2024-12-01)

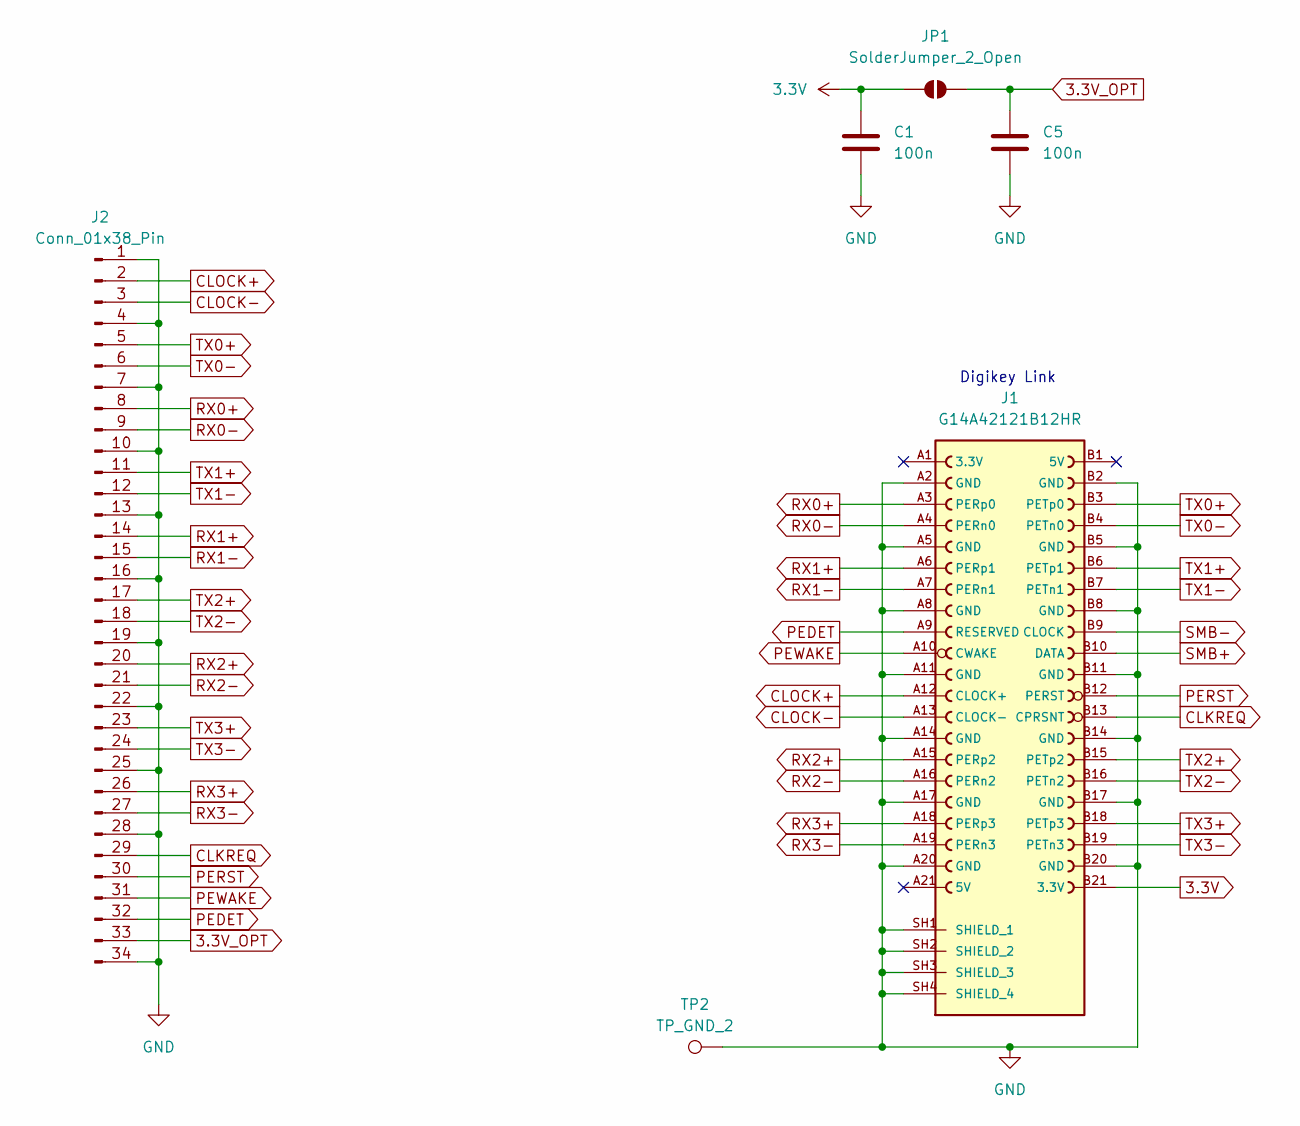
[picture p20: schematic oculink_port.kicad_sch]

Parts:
C1, C5: 100n; C_0402_1005Metric; LCSC Part C513772
J1: G14A42121B12HR; AMPHENOL_G14A42121B12HR; PARTREV D; LCSC Part C5156927
J2: Conn_01x38_Pin; port_pcb
JP1: SolderJumper_2_Open; SolderJumper-2_P1.3mm_Open_RoundedPad1.0x1.5mm
TP2: TP_GND_2; TestPoint_Pad_D1.0mm

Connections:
3.3V: C1.1, J1.B21 (3.3V), JP1.1 (A)
3.3V_OPT: C5.1, J2.33, JP1.2 (B)
CLKREQ: J1.B13 (CPRSNT), J2.29
CLOCK+: J1.A12 (CLOCK+), J2.2
CLOCK-: J1.A13 (CLOCK-), J2.3
GND: C1.2, C5.2, J1.A2 (GND), J1.A5 (GND), J1.A8 (GND), J1.A11 (GND), J1.A14 (GND), J1.A17 (GND), J1.A20 (GND), J1.B2 (GND), J1.B5 (GND), J1.B8 (GND), J1.B11 (GND), J1.B14 (GND), J1.B17 (GND), J1.B20 (GND), J1.SH1 (SHIELD_1), J1.SH2 (SHIELD_2), J1.SH3 (SHIELD_3), J1.SH4 (SHIELD_4), J2.1, J2.4, J2.7, J2.10, J2.13, J2.16, J2.19, J2.22, J2.25, J2.28, J2.34, TP2.1
PEDET: J1.A9 (RESERVED), J2.32
PERST: J1.B12 (PERST), J2.30
PEWAKE: J1.A10 (CWAKE), J2.31
RX0+: J1.A3 (PERp0), J2.8
RX0-: J1.A4 (PERn0), J2.9
RX1+: J1.A6 (PERp1), J2.14
RX1-: J1.A7 (PERn1), J2.15
RX2+: J1.A15 (PERp2), J2.20
RX2-: J1.A16 (PERn2), J2.21
RX3+: J1.A18 (PERp3), J2.26
RX3-: J1.A19 (PERn3), J2.27
SMB+: J1.B10 (DATA)
SMB-: J1.B9 (CLOCK)
TX0+: J1.B3 (PETp0), J2.5
TX0-: J1.B4 (PETn0), J2.6
TX1+: J1.B6 (PETp1), J2.11
TX1-: J1.B7 (PETn1), J2.12
TX2+: J1.B15 (PETp2), J2.17
TX2-: J1.B16 (PETn2), J2.18
TX3+: J1.B18 (PETp3), J2.23
TX3-: J1.B19 (PETn3), J2.24

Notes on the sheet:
Digikey Link

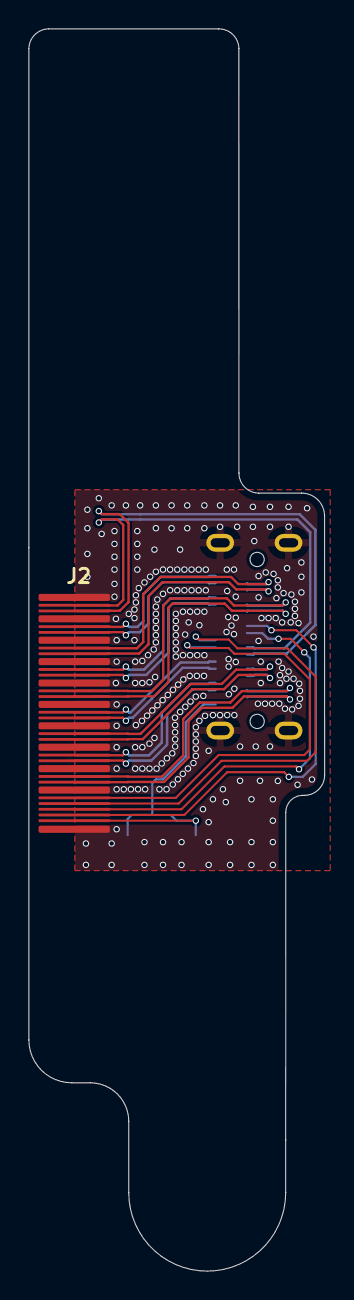
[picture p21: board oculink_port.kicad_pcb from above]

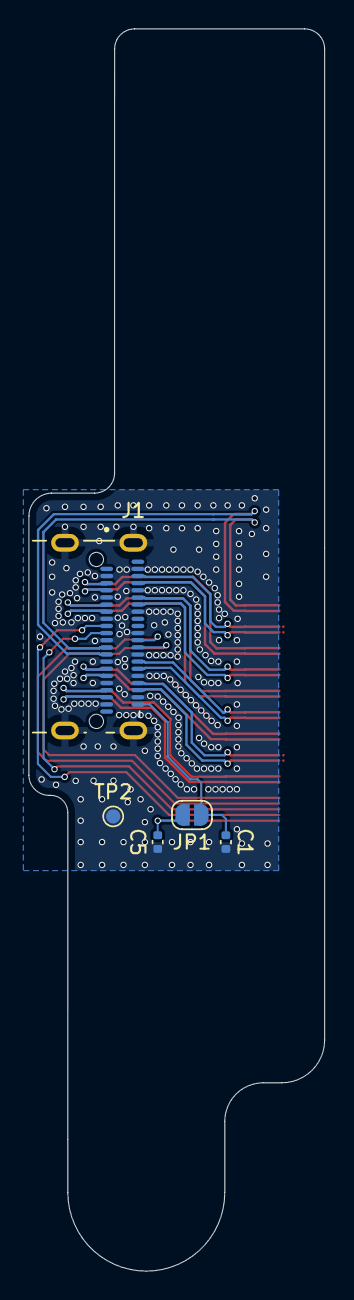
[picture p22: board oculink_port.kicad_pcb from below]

Board: 4 copper layers, 20.7 x 87.1 mm, 6 parts (6 on the bottom side), 25 nets.

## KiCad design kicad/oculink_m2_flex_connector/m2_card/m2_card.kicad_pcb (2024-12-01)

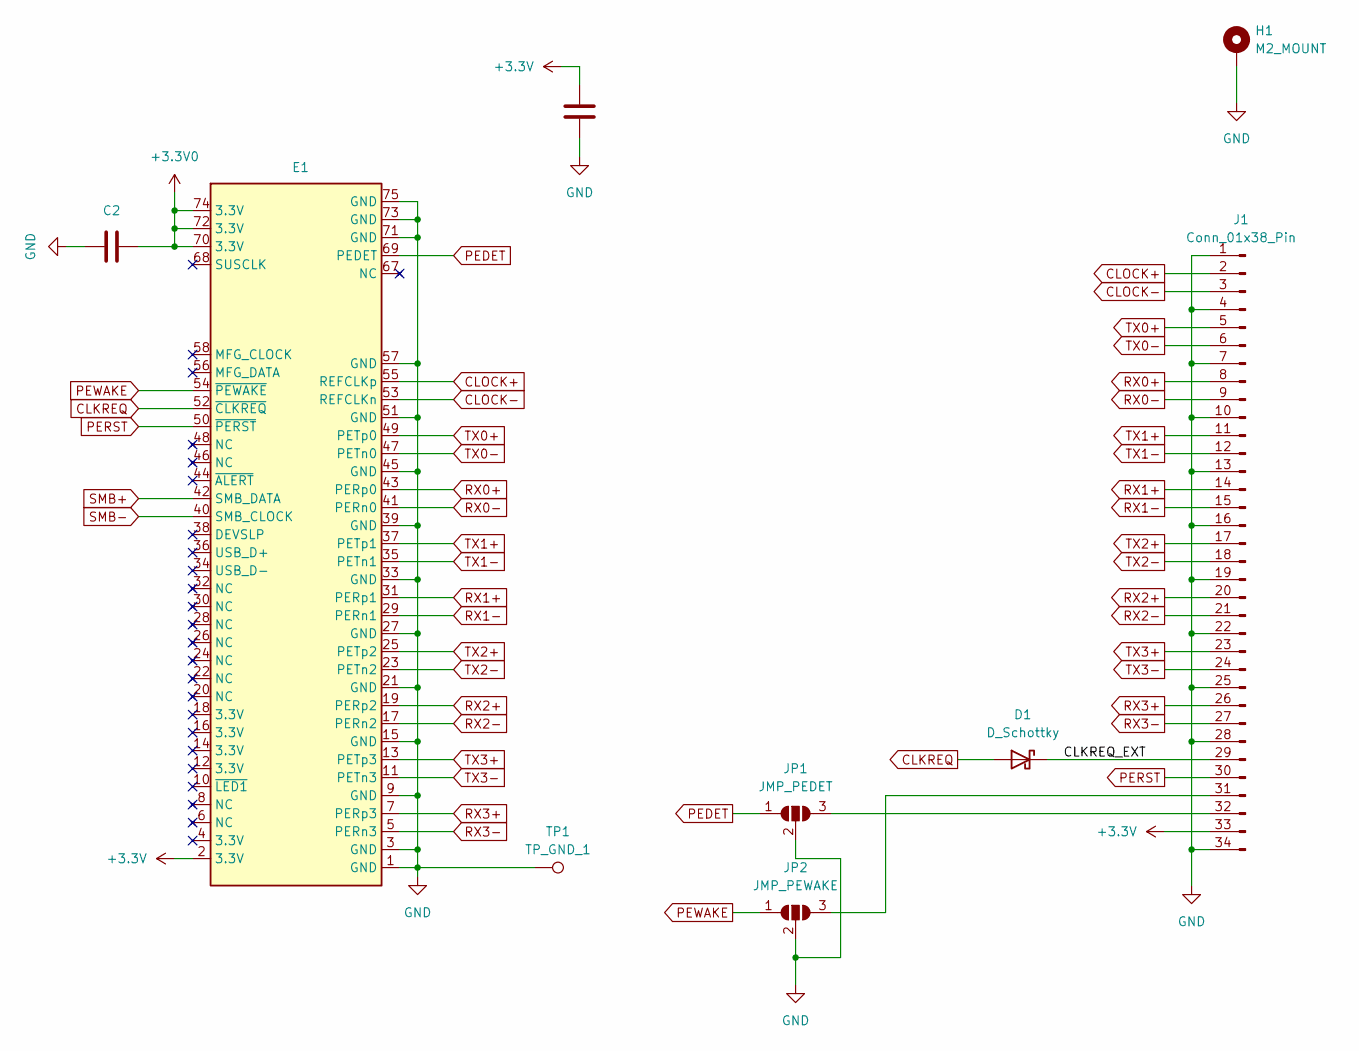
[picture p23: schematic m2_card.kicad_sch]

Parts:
C1, C2: 100n; C_0402_1005Metric; LCSC Part C513772
D1: D_Schottky; D_SOD-523; LCSC Part C475624
E1: m2_m_key
H1: M2_MOUNT; m2_ground_hole
J1: Conn_01x38_Pin; port_pcb
JP1: JMP_PEDET; 3pin_4state_jumper
JP2: JMP_PEWAKE; 3pin_4state_jumper
TP1: TP_GND_1; TestPoint_Pad_D1.0mm

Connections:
+3.3V: C1.1, E1.2 (3.3V), J1.33
+3.3V0: C2.2, E1.70 (3.3V), E1.72 (3.3V), E1.74 (3.3V)
/CLKREQ_EXT: D1.1 (K), J1.29
CLKREQ: D1.2 (A), E1.52 (~CLKREQ)
CLOCK+: E1.55 (REFCLKp), J1.2
CLOCK-: E1.53 (REFCLKn), J1.3
GND: C1.2, C2.1, E1.1 (GND), E1.3 (GND), E1.9 (GND), E1.15 (GND), E1.21 (GND), E1.27 (GND), E1.33 (GND), E1.39 (GND), E1.45 (GND), E1.51 (GND), E1.57 (GND), E1.71 (GND), E1.73 (GND), E1.75 (GND), H1.1, J1.1, J1.4, J1.7, J1.10, J1.13, J1.16, J1.19, J1.22, J1.25, J1.28, J1.34, JP1.2 (C), JP2.2 (C), TP1.1
unnamed: J1.31, JP2.3 (B)
unnamed: J1.32, JP1.3 (B)
PEDET: E1.69 (PEDET), JP1.1 (A)
PERST: E1.50 (~PERST), J1.30
PEWAKE: E1.54 (~PEWAKE), JP2.1 (A)
RX0+: E1.43 (PERp0), J1.8
RX0-: E1.41 (PERn0), J1.9
RX1+: E1.31 (PERp1), J1.14
RX1-: E1.29 (PERn1), J1.15
RX2+: E1.19 (PERp2), J1.20
RX2-: E1.17 (PERn2), J1.21
RX3+: E1.7 (PERp3), J1.26
RX3-: E1.5 (PERn3), J1.27
SMB+: E1.42 (SMB_DATA)
SMB-: E1.40 (SMB_CLOCK)
TX0+: E1.49 (PETp0), J1.5
TX0-: E1.47 (PETn0), J1.6
TX1+: E1.37 (PETp1), J1.11
TX1-: E1.35 (PETn1), J1.12
TX2+: E1.25 (PETp2), J1.17
TX2-: E1.23 (PETn2), J1.18
TX3+: E1.13 (PETp3), J1.23
TX3-: E1.11 (PETn3), J1.24

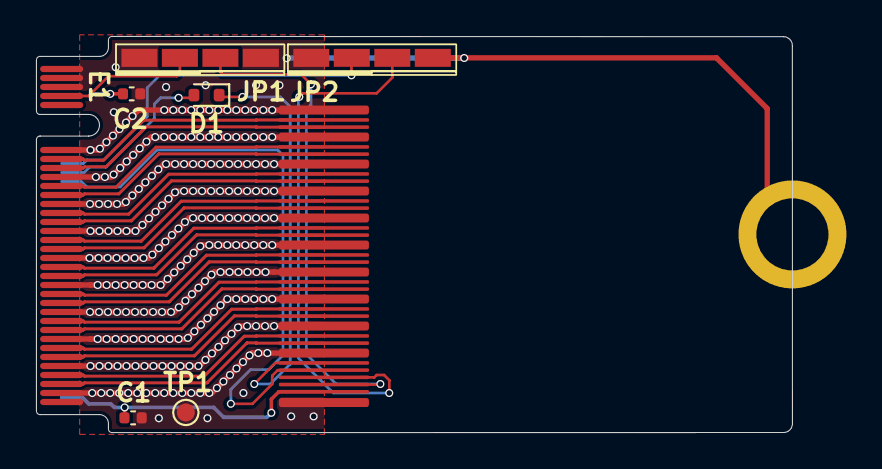
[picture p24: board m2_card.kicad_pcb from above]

Board: 4 copper layers, 42.0 x 22.0 mm, 9 parts (1 on the bottom side), 28 nets.

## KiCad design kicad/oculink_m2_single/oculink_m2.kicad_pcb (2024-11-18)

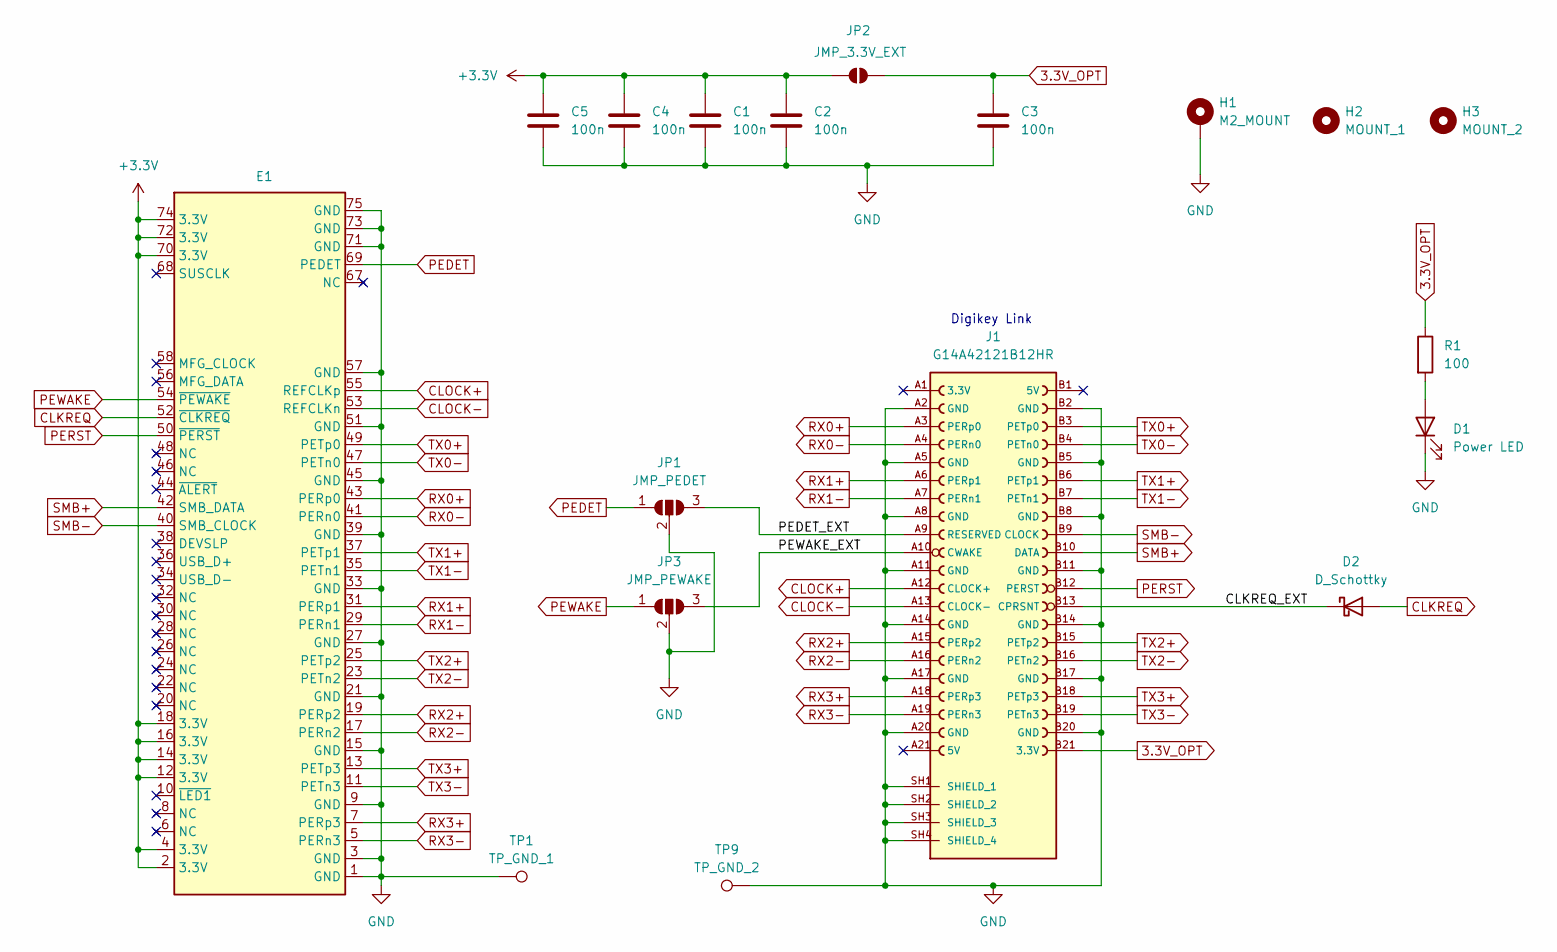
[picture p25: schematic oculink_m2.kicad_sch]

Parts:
C1, C2, C3, C4, C5: 100n; C_0402_1005Metric; LCSC Part C513772
D1: Power LED; LED_1206_3216Metric_Pad1.42x1.75mm_HandSolder; LCSC Part C434442
D2: D_Schottky; D_SOD-523; LCSC Part C475624
E1: m2_m_key
H1: M2_MOUNT; m2_ground_hole
H2: MOUNT_1; secondary_mounting_hole
H3: MOUNT_2; secondary_mounting_hole
J1: G14A42121B12HR; AMPHENOL_G14A42121B12HR; PARTREV D; LCSC Part C5156927
JP1: JMP_PEDET; 3pin_4state_jumper
JP2: JMP_3.3V_EXT; SolderJumper-2_P1.3mm_Open_RoundedPad1.0x1.5mm
JP3: JMP_PEWAKE; 3pin_4state_jumper
R1: 100; R_0603_1608Metric; LCSC Part C22775
TP1: TP_GND_1; TestPoint_Pad_D1.0mm
TP9: TP_GND_2; TestPoint_Pad_D1.0mm

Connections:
3.3V_OPT: C3.1, J1.B21 (3.3V), JP2.2 (B), R1.1
+3.3V: C1.1, C2.1, C4.1, C5.1, E1.2 (3.3V), E1.4 (3.3V), E1.12 (3.3V), E1.14 (3.3V), E1.16 (3.3V), E1.18 (3.3V), E1.70 (3.3V), E1.72 (3.3V), E1.74 (3.3V), JP2.1 (A)
/CLKREQ_EXT: D2.1 (K), J1.B13 (CPRSNT)
/PEDET_EXT: J1.A9 (RESERVED), JP1.3 (B)
/PEWAKE_EXT: J1.A10 (CWAKE), JP3.3 (B)
CLKREQ: D2.2 (A), E1.52 (~CLKREQ)
CLOCK+: E1.55 (REFCLKp), J1.A12 (CLOCK+)
CLOCK-: E1.53 (REFCLKn), J1.A13 (CLOCK-)
GND: C1.2, C2.2, C3.2, C4.2, C5.2, D1.1 (K), E1.1 (GND), E1.3 (GND), E1.9 (GND), E1.15 (GND), E1.21 (GND), E1.27 (GND), E1.33 (GND), E1.39 (GND), E1.45 (GND), E1.51 (GND), E1.57 (GND), E1.71 (GND), E1.73 (GND), E1.75 (GND), H1.1, J1.A2 (GND), J1.A5 (GND), J1.A8 (GND), J1.A11 (GND), J1.A14 (GND), J1.A17 (GND), J1.A20 (GND), J1.B2 (GND), J1.B5 (GND), J1.B8 (GND), J1.B11 (GND), J1.B14 (GND), J1.B17 (GND), J1.B20 (GND), J1.SH1 (SHIELD_1), J1.SH2 (SHIELD_2), J1.SH3 (SHIELD_3), J1.SH4 (SHIELD_4), JP1.2 (C), JP3.2 (C), TP1.1, TP9.1
unnamed: D1.2 (A), R1.2
PEDET: E1.69 (PEDET), JP1.1 (A)
PERST: E1.50 (~PERST), J1.B12 (PERST)
PEWAKE: E1.54 (~PEWAKE), JP3.1 (A)
RX0+: E1.43 (PERp0), J1.A3 (PERp0)
RX0-: E1.41 (PERn0), J1.A4 (PERn0)
RX1+: E1.31 (PERp1), J1.A6 (PERp1)
RX1-: E1.29 (PERn1), J1.A7 (PERn1)
RX2+: E1.19 (PERp2), J1.A15 (PERp2)
RX2-: E1.17 (PERn2), J1.A16 (PERn2)
RX3+: E1.7 (PERp3), J1.A18 (PERp3)
RX3-: E1.5 (PERn3), J1.A19 (PERn3)
SMB+: E1.42 (SMB_DATA), J1.B10 (DATA)
SMB-: E1.40 (SMB_CLOCK), J1.B9 (CLOCK)
TX0+: E1.49 (PETp0), J1.B3 (PETp0)
TX0-: E1.47 (PETn0), J1.B4 (PETn0)
TX1+: E1.37 (PETp1), J1.B6 (PETp1)
TX1-: E1.35 (PETn1), J1.B7 (PETn1)
TX2+: E1.25 (PETp2), J1.B15 (PETp2)
TX2-: E1.23 (PETn2), J1.B16 (PETn2)
TX3+: E1.13 (PETp3), J1.B18 (PETp3)
TX3-: E1.11 (PETn3), J1.B19 (PETn3)

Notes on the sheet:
Digikey Link

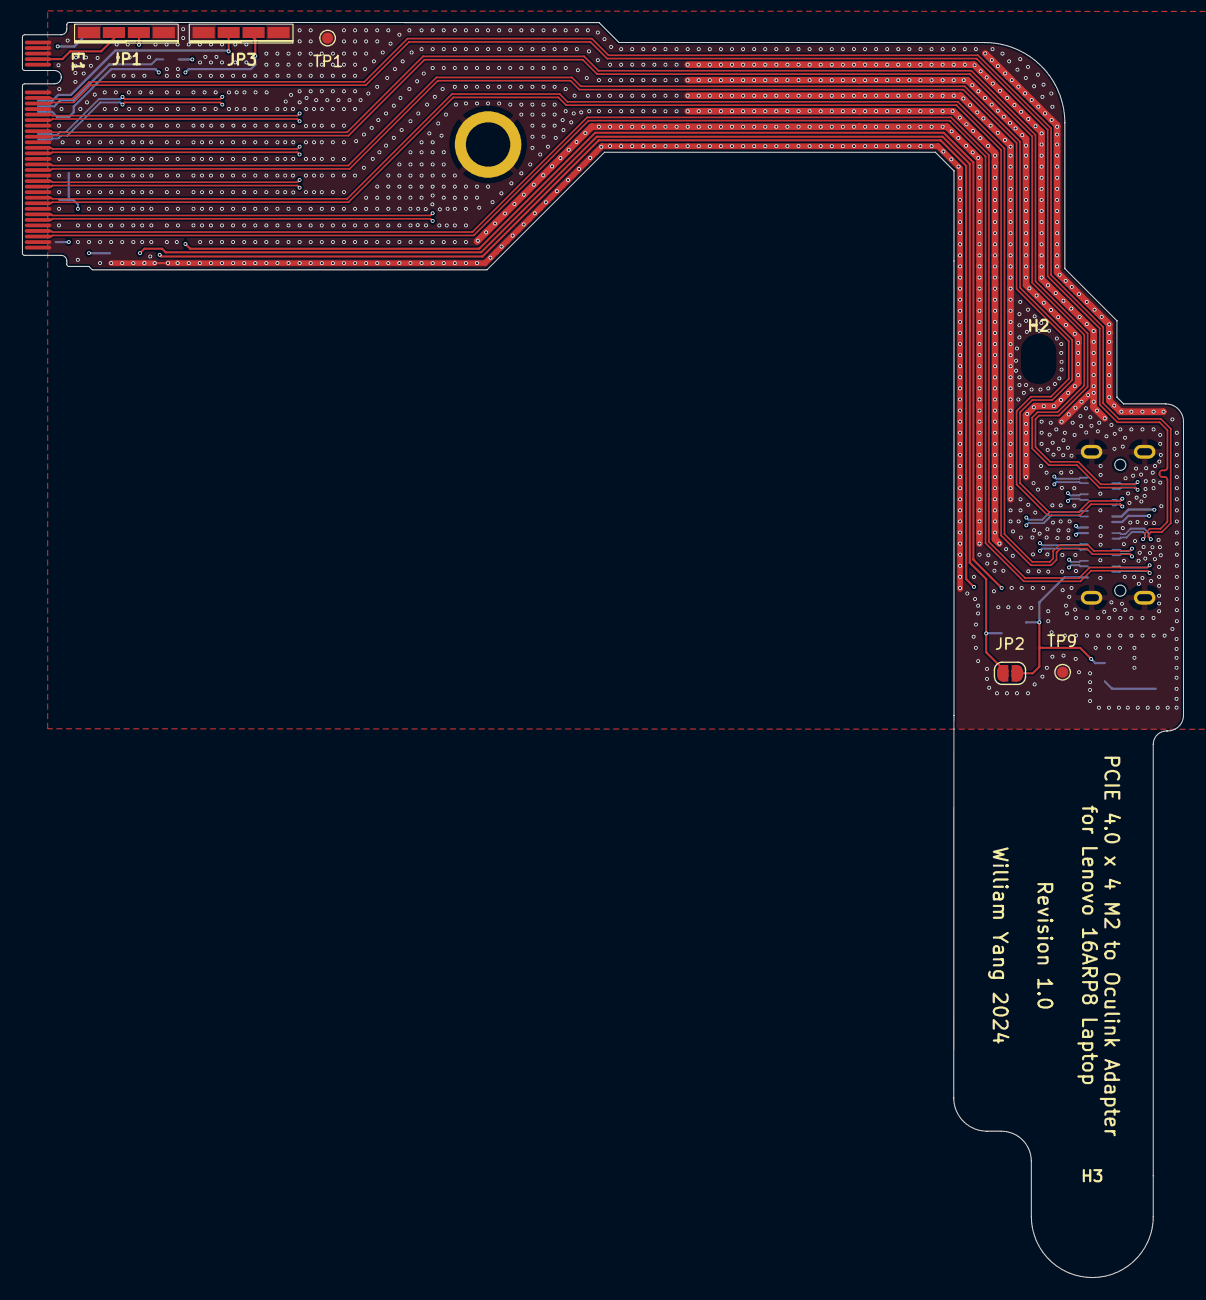
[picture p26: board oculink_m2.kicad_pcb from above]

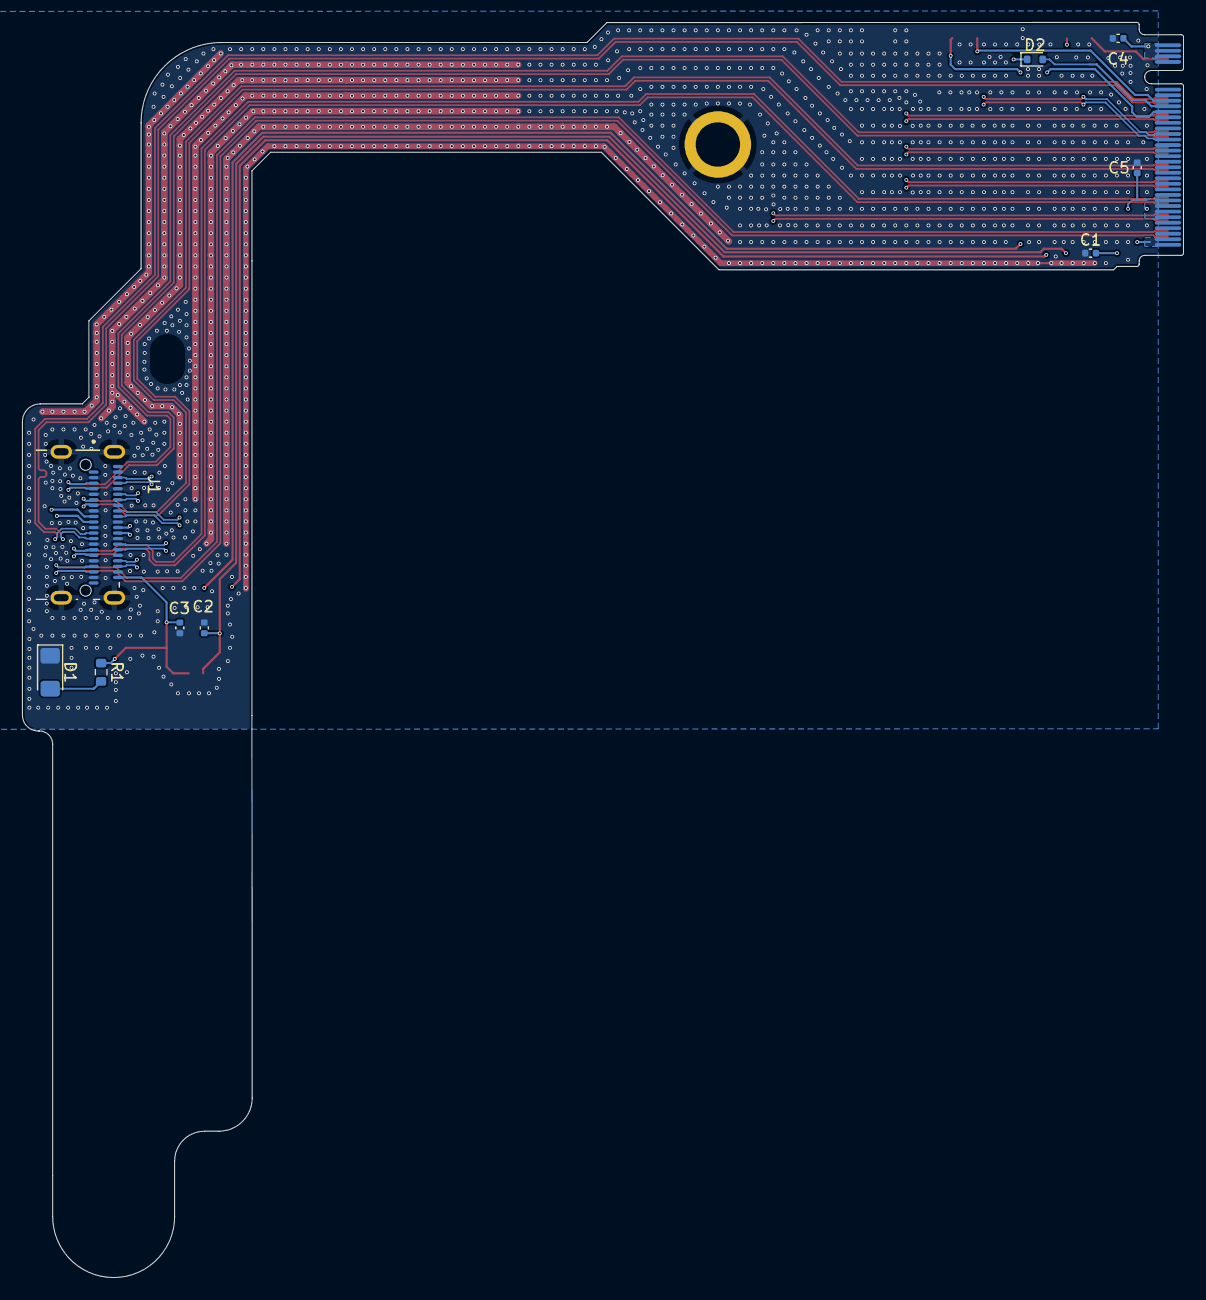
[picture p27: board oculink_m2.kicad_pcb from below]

Board: 4 copper layers, 104.7 x 113.2 mm, 18 parts (9 on the bottom side), 31 nets.

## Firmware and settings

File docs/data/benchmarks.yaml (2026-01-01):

3d_mark:
  - name: PCIe Bandwidth (GB/s)
    amd_680m:
      score: 11.20
      path: 3dmark_pcie_bandwidth_amd_680m.png
    amd_5700xt_pcie3:
      score: 3.53
      path: 3dmark_pcie_bandwidth_flex_pcb.png
    amd_5700xt_pcie4:
      score: 6.39
      path: 3dmark_pcie_bandwidth_amd_5700xt.png
    nvidia_5060ti_pcie4:
      score: 7.22 
      path: 3dmark_pcie_bandwidth_nvidia_5060ti.png
  - name: Fire Strike
    amd_680m:
      score: 6155
      path: 3dmark_fire_strike_amd_680m.png
    amd_5700xt_pcie3:
      score: 19512
      path: 3dmark_fire_strike_flex_pcb.png
    amd_5700xt_pcie4:
      score: 23577
      path: 3dmark_fire_strike_amd_5700xt.png
    nvidia_5060ti_pcie4:
      score: 29857
      path: 3dmark_fire_strike_nvidia_5060ti.png
  - name: Night Raid
    amd_680m:
      score: 23554
      path: 3dmark_night_raid_amd_680m.png
    amd_5700xt_pcie3:
      score: 35831
      path: 3dmark_night_raid_flex_pcb.png
    amd_5700xt_pcie4:
      score: 52358
      path: 3dmark_night_raid_amd_5700xt.png
    nvidia_5060ti_pcie4:
      score: 51534
      path: 3dmark_night_raid_nvidia_5060ti.png
  - name: Steel Nomad
    amd_680m:
      score: 444 
      path: 3dmark_steel_nomad_amd_680m.png
    amd_5700xt_pcie3:
      score: 1950
      path: 3dmark_steel_nomad_flex_pcb.png
    amd_5700xt_pcie4:
      score: 2030
      path: 3dmark_steel_nomad_amd_5700xt.png
    nvidia_5060ti_pcie4:
      score: 3539
      path: 3dmark_steel_nomad_nvidia_5060ti.png
  - name: Steel Nomad Light
    amd_680m:
      score: 2308
      path: 3dmark_steel_nomad_light_amd_680m.png
    amd_5700xt_pcie3:
      score: 7299
      path: 3dmark_steel_nomad_light_flex_pcb.png
    amd_5700xt_pcie4:
      score: 8218
      path: 3dmark_steel_nomad_light_amd_5700xt.png
    nvidia_5060ti_pcie4:
      score: 16101
      path: 3dmark_steel_nomad_light_nvidia_5060ti.png
  - name: Time Spy
    amd_680m:
      score: 2762
      path: 3dmark_time_spy_amd_680m.png
    amd_5700xt_pcie3:
      score: 8093
      path: 3dmark_time_spy_flex_pcb.png
    amd_5700xt_pcie4:
      score: 9051
      path: 3dmark_time_spy_amd_5700xt.png
    nvidia_5060ti_pcie4:
      score: 12884
      path: 3dmark_time_spy_nvidia_5060ti.png
  - name: Wild Life
    amd_680m:
      score: 15622
      path: 3dmark_wild_life_amd_680m.png
    amd_5700xt_pcie3:
      score: 35637
      path: 3dmark_wild_life_flex_pcb.png
    amd_5700xt_pcie4:
      score: 54329
      path: 3dmark_wild_life_amd_5700xt.png
    nvidia_5060ti_pcie4:
      score: 82375
      path: 3dmark_wild_life_nvidia_5060ti.png
  - name: Wild Life Extreme
    amd_680m:
      score: 4523
      path: 3dmark_wild_life_extreme_amd_680m.png
    amd_5700xt_pcie3:
      score: 15497
      path: 3dmark_wild_life_extreme_flex_pcb.png
    amd_5700xt_pcie4:
      score: 18682
      path: 3dmark_wild_life_extreme_amd_5700xt.png
    nvidia_5060ti_pcie4:
      score: 30230
      path: 3dmark_wild_life_extreme_nvidia_5060ti.png
aida64:
  amd_680m:
    read_pinned: 34.1
    read_pageable: 11.7
    write_pinned: 35.2
    write_pageable: 13.1
    path: aida64_detailed_amd_680m.png
  amd_5700xt_pcie3:
    read_pinned: 3.38
    read_pageable: 2.78
    write_pinned: 3.37
    write_pageable: 2.71
    path: aida64_detailed_flex_pcb.png
  amd_5700xt_pcie4:
    read_pinned: 6.70
    read_pageable: 4.74
    write_pinned: 6.71
    write_pageable: 4.74
    path: aida64_detailed_amd_5700xt.png
  nvidia_5060ti_pcie4:
    read_pinned: 6.78
    read_pageable: 5.53
    write_pinned: 6.84
    write_pageable: 6.67
    path: aida64_detailed_nvidia_5060ti.png
furmark2:
  - name: Donut OpenGL
    amd_680m:
      score: 1797
      path: furmark2_donut_gl_amd_680m.png
    amd_5700xt_pcie3:
      score: 6513
      path: furmark2_donut_gl_flex_pcb.png
    amd_5700xt_pcie4:
      score: 8015
      path: furmark2_donut_gl_amd_5700xt.png
    nvidia_5060ti_pcie4:
      score: 11428
      path: furmark2_donut_gl_nvidia_5060ti.png
  - name: Donut Vulkan
    amd_680m:
      score: 1370
      path: furmark2_donut_vk_amd_680m.png
    amd_5700xt_pcie3:
      score: 6037
      path: furmark2_donut_vk_flex_pcb.png
    amd_5700xt_pcie4:
      score: 7453
      path: furmark2_donut_vk_amd_5700xt.png
    nvidia_5060ti_pcie4:
      score: 11959
      path: furmark2_donut_vk_nvidia_5060ti.png
  - name: Knot OpenGL
    amd_680m:
      score: 618
      path: furmark2_knot_gl_amd_680m.png
    amd_5700xt_pcie3:
      score: 2208
      path: furmark2_knot_gl_flex_pcb.png
    amd_5700xt_pcie4:
      score: 2226
      path: furmark2_knot_gl_amd_5700xt.png
    nvidia_5060ti_pcie4:
      score: 4151
      path: furmark2_knot_gl_nvidia_5060ti.png
  - name: Knot Vulkan
    amd_680m:
      score: 641
      path: furmark2_knot_vk_amd_680m.png
    amd_5700xt_pcie3:
      score: 3063
      path: furmark2_knot_vk_flex_pcb.png
    amd_5700xt_pcie4:
      score: 3393
      path: furmark2_knot_vk_amd_5700xt.png
    nvidia_5060ti_pcie4:
      score: 6118
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

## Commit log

2024-09-22 Updated footprints
2024-09-22 Fixed dimensions of m2 connector
2024-09-22 Removed mounting hole from footprint
2024-09-22 Added mounting hole as separate component
2024-09-23 Updated edge connector pinout
2024-09-23 Update m2 connector pinout from adtlink schematic
2024-09-24 Temporary mockup of adtlink adapter
    [oculink_m2.kicad_pcb, oculink_m2.kicad_sch]
2024-09-24 Preliminary routing of pcie lanes over bottleneck in pcb
    [oculink_m2.kicad_pcb, oculink_m2.kicad_sch]
2024-09-24 Finished prototype of potentially ready adapter
    [oculink_m2.kicad_pcb, oculink_m2.kicad_sch]
2024-09-24 Updated with jlcpcb plot settings
    [oculink_m2.kicad_pcb]
2024-09-24 Fixed soldermask layer revealing a pcie trace
    [oculink_m2.kicad_pcb]
2024-09-24 Improved ground stitching and fix skew on clock differential pair
    [oculink_m2.kicad_pcb]
2024-09-25 Swapped SMB pair to connect clock/data correctly
    [oculink_m2.kicad_pcb, oculink_m2.kicad_sch]
2024-09-25 Updated impedance calculations with sierra circuits values and jlcpcb datasheet
2024-09-26 Added additional mounting holes for adapter
    [oculink_m2.kicad_pcb, oculink_m2.kicad_sch]
2024-09-26 Fixed position of additional mounting holes and made them oval vertically for potential vertical adjustment of adapter
    [oculink_m2.kicad_pcb]
2024-09-26 Fixed ground pour overflowing onto m2 edge connector
    [oculink_m2.kicad_pcb]
2024-09-28 Added stackup information to schematic
    [oculink_m2.kicad_pcb]
2024-09-28 Added soldermask web between pads to prevent solder bridging during smd assembly
2024-09-28 Fixed mounting holes
    [oculink_m2.kicad_pcb, oculink_m2.kicad_sch]
2024-09-28 Added bill of material and smd parts positioning scripts
    [oculink_m2.kicad_pcb, oculink_m2.kicad_sch]
2024-09-28 Updated bom script and added in schottky diode on clkreq
    [oculink_m2.kicad_pcb, oculink_m2.kicad_sch]
2024-09-28 Production pcb ordered to jlcpcb
    [oculink_m2.kicad_pcb, oculink_m2.kicad_sch]
2024-09-28 Cleanup traces
    [oculink_m2.kicad_pcb]
2024-09-29 Added design rule check for 85ohm impedance matched differential pairs
    [oculink_m2.kicad_pcb]
2024-09-29 Fixed up diff pair custom rules
    [oculink_m2.kicad_pcb]
2024-10-20 Moved custom components to separate folder
    [G14A421211112HR.step, G14A42121B12HR.step, oculink_m2.kicad_pcb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]
2024-11-18 Added flex pcb design
    [flex_pcb.kicad_pcb, flex_pcb.kicad_sch, m2_card.kicad_pcb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]
2024-11-28 Initial layout of port side board
    [oculink_port.kicad_pcb, oculink_port.kicad_sch]
2024-11-28 Set correct impedance on port pcb
    [oculink_port.kicad_pcb]
2024-11-28 Finished first draft of m2 card
    [m2_card.kicad_pcb, m2_card.kicad_sch]
2024-11-28 Crude flex pcb layout
    [flex_pcb.kicad_pcb, flex_pcb.kicad_sch]
2024-11-28 Test design for consistent hatched ground plane
    [flex_pcb.kicad_pcb]
2024-11-29 Unified taper geometry across pcbs
    [flex_pcb.kicad_pcb, m2_card.kicad_pcb, oculink_port.kicad_pcb]
2024-11-29 Added taper for ground ffc pads
    [flex_pcb.kicad_pcb, m2_card.kicad_pcb, oculink_port.kicad_pcb]
2024-12-01 Added mounting for port
    [oculink_port.kicad_pcb]
2024-12-01 Shifted location of ffc connector to avoid screw mount
    [oculink_port.kicad_pcb]
2024-12-01 Initial design and layout for flex pcb
    [flex_pcb.kicad_pcb]
2024-12-01 Finished initial layout of hatched plane for differential traces
    [flex_pcb.kicad_pcb]
2024-12-01 Finished via fencing on flex pcb
    [flex_pcb.kicad_pcb]
2024-12-01 Added design rule checks to m2 card pcb
    [m2_card.kicad_pcb]
2024-12-01 Generate plots for manufacturing
    [flex_pcb.kicad_pcb, m2_card.kicad_pcb, oculink_port.kicad_pcb]
2025-01-10 Added flex pcb benchmarks
2025-02-02 Added gerber2ems in simulation folder
2025-02-02 Added hatched ground plane simulation setup
    [differential.kicad_pcb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]
2025-02-04 Generate debug image for hatched ground plane
2025-02-04 Added differential taper parametric search
    [differential-B_Cu.gbr, differential-Edge_Cuts.gbr, differential-F_Cu.gbr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]
2025-02-06 Updated taper simulation
    [differential.kicad_pcb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]
2025-02-06 Updated trace width to 0.15mm instead of 0.1mm
    [differential.kicad_pcb, differential.kicad_sch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]
